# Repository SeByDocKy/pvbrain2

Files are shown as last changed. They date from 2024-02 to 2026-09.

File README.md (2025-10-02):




# PVbrainV2

pvbrain_v2_logo

> [!IMPORTANT]
> <sub></sub> is an open source/openhardware project to monitor/control __`SIMULTANEOUSLY`__ :
> - Multiple inverters. <sup>`(PIPsolar/Voltronic, Deye, Growatt, Sofar, Victron, etc...)`</sup> 
> - And multiple BMS. <sup>`(JKBMS, AntBMS, DalyBMS, SeplosBMS, Pylontech, etc...)`</sup>
> 
> <sup>-> _In theory any inverter or BMS with ESPhome support can be used with the PVbrain2._</sup>
> 
> It also adds the possibility of controlling up to 32 relays allowing for example to control an **A**utomatic **T**ransfer **S**witch <sup>(ATS)</sup> _(Offgrid<=>return to the network)_. 
> 
> The PCB uses only crossover components or pluggable components in order to have easy setup/maintenance. 
> 
> The MCU used is an [ESP32S3](https://s.click.aliexpress.com/e/_DCEPtOd) running <sub></sub> allowing communication over WiFi to <sub></sub> <sup>(HA)</sup> natively.<br/>
> <sup>-> _But </sup><sup> can be added easily._</sup>
> 
> __The main features are :__
> - [x] Direct communication and control with Voltronic/Pipsolar, DEYE, SOFAR, GROWATT inverters via direct Ethernet cable.<br/> <sup>_(pvbrain has a built-in [RS232](https://a.aliexpress.com/_EzMcqvP) and [RS485](https://a.aliexpress.com/_EzS7TkZ)  => TTL)_</sup>
> - [x] CANbus support. Possibility to translate informations from old generation BMS into modern CANbus protocols (Pylontech 1.2, Pylontech +, SMA, Victron)
> - [x] The VEdirect for <sub></sub> models with an insulated adapter provided. 
> - [x] Important settings can be set directly from HA <sup>_(or the web server if enabled)_</sup>.
> - [x] Monitor multiple BMS <sup>_(tested with JKBMS but should work with antBMS, DalyBMS, PaceBMS or SeplosBMS)_</sup> with an insulated adapter provided.
> - [x] Detect multiple AC sources <sup>_(solar/network/other)_</sup> via optocoupler modules (in order for example to do soft switching for the ATS part).
> - [x] Monitor _via_ a [JSY193](https://a.aliexpress.com/_EyMD1XJ), [JSY194T](https://a.aliexpress.com/_EHWOhZb) module <sup>_(modbus)_</sup> solar and network production.
> - [x] Monitor _via_ a [JSY231](https://aliexpress.com/item/1005007472236141.html), [Smartshunt](https://www.amazon.fr/VICTRON-ENERGY-SmartShunt-Contr%C3%B4leur-SHU050150050/dp/B0856PHNLX/ref=sr_1_1) module <sup>_(modbus)_</sup> and <sup>_(VE.direct)_</sup> battery energetic flows
> - [x] Control up to 32x relays with two i2c extension [SX1509](https://esphome.io/components/sx1509), _that is_ for ATS control or the reversing mode of a modern inverter.<br/> <sup>_(Axpert max I & II for example)_</sup>
> - [x] A solar power diverter for pure resistive loads (eg. hot water tank) thanks to [ROBOTDYN](https://a.aliexpress.com/_EwiP2jL) or [SSR](https://a.aliexpress.com/_EyikzBP) modules controlled in PWM, 0-10V. Can be easily extented for Modbus RTU model.
> - [x] Smart EVSE regulation _for_ a [ETEK ekepc2](https://fr.aliexpress.com/item/1005007472236141.html) module with AC active power, DC battery current or Pyranometer informations
> - [x] Monitor your basement temperature/humidity/pressure with [BME280](https://esphome.io/components/sensor/bme280) <sup>_(you can set up alarms just in case)_</sup>.
> - [x] Free I2C ports available for plugging in additional I2C sensors.
> - [x] SPI port is also available.

> [!NOTE]
> This PCB uses the excellent ESPhome integrations done by :
> - <sub></sub> (Many BMS and inverter).
> - <sub></sub> (Expansion cards [WK2132](https://www.dfrobot.com/product-2001.html) and [WK2168](../main/hardware/module_wk_2168/wk2168_3d_view.png) ).
> 
> The __PVbrain 2.0__ represents a joint work between <sub></sub> of the <sub></sub> and <sub></sub>.
> - With the help of several members of the <sub></sub>.

**For more information on the project, the pcb, the code and their use, please refer to the [wiki](https://github.com/SeByDocKy/pvbrain2/wiki).**

# Release PVbrain 2 Youtube Live event:
youtube_live (https://www.youtube.com/watch?v=e8uBhS54MFE)
<br/>_Video in French._

# Software (ESPhome) installation steps:
- __First of all be sure you have installed on your machine the ESP32 S3 driver from [Sillicon Labs](https://www.silabs.com/developers/usb-to-uart-bridge-vcp-drivers?tab=downloads).__

__Classic procedure :__

> <details>
><summary>Click here for show the Classic procedure. :arrow_heading_down:</summary>
> 
> :back:
> - :one: :heavy_minus_sign: Retrieve the [PVbrain 2.0](https://github.com/SeByDocKy/pvbrain2/archive/refs/heads/main.zip) zip (by right clicking) and save it into a new created folder, eg. /pvbrain2
> - :two: :heavy_minus_sign: Uncompress the zip file into your local folder (/pvbrain2) or into your/config/esphome folder of HASSIO (use samba share to transfer the uncompressed files).
> - :three: :heavy_minus_sign: Open your esphome's secrets.yaml file and check if wifi_ssid, wifi_password and ap_password variables are correctly corresponding with your local WiFi informations. 
> - :four: :heavy_minus_sign: Edit the PVbrain2.yaml and comment/uncomment each package according to your own solar setup. 
> - :five: :heavy_minus_sign: Compile and upload the code on your ESP32 S3 device.
> </details>

__Dummy procedure (for newbabies) :__

> <details>
><summary>Click here for show the Dummy procedure. :arrow_heading_down:</summary>
>
> :back:
> - :one: :heavy_minus_sign: Create/sign in a [Github](https://github.com/) accompt. You can create it faster with OAuth2 via your google account for example. 
> - :two: :heavy_minus_sign: Open the following [Gitpod](https://gitpod.io/#https://github.com/SeByDocKy/pvbrain2/tree/main) link. 
>   - The first time you will need also to sign in into gitpod framework for example with your previously created Github account.
> - :three: :heavy_minus_sign: When logged into Gitpod, you will see during the ESPhome installation, some log lines printed in the terminal. 
>   - Wait a couples of minutes to let finish the processus. 
>   - When done, press the "Open Browser" located at the botton right of the Gitpod page. 
>   - It should open a new webpage with the ESPhome Dashboard.
> - :four: :heavy_minus_sign: On the ESPhome Dashboard, click first on "secret" button located at the top right corner. 
>   - Replace "xxxxxxxx", "yyyyyyyy" and "zzzzzzzz" with your own WiFi SSID/password and AP informations (AP password will allow to access to your PVbrain2 if your WiFi/LAN is down). 
>   - Be aware, WiFi password must be a minimum of 8 caractars. 
>     - If not, you will need to change your WiFi password correspondly. 
>   - Click on "save" and quit the secret page by clicking on the top left cross.
> - :five: :heavy_minus_sign: Click on "Edit" for the PVbrain2 model. 
>   - Comment and/or uncomment each package according to your own solar setup and save the file. (Tip: you can comment/uncomment several lines simultaneously by selecting the lines and press on CTRL + /)
> - :six: :heavy_minus_sign: Plug your ESP32-S3 with a USB data cable first then the on top right corner, choose "Install" then on "Plug into this computer" to compile the firmware. It can be a long processus !!!. 
>   - Wait a couple of minutes (it first compile the code at background during 3-4min) then it starts the flashing part. 
>     - You should see a progression bar running when flashing.
> - :seven: :heavy_minus_sign: You finished the flashing procedure. 
>   - If you entered correctly your WiFi informations in the secrets.yaml file, you should see a notification in Home Assistant asking you to accept a new ESPhome device. 
>   - Accept it... __You finished!!!!__
> </details>

> <details>
><summary>Click here for show the French YouTube video of the Dummy procedure. :arrow_heading_down:</summary>
>
> :back:
>
> youtube_Dummy_procedure (https://www.youtube.com/watch?v=R9PXNV0ayU4)
> <br/>_Video in French._
> </details>

# Main PCB Layout :

| 3D View | Copper Area |
| :---: | :---: |
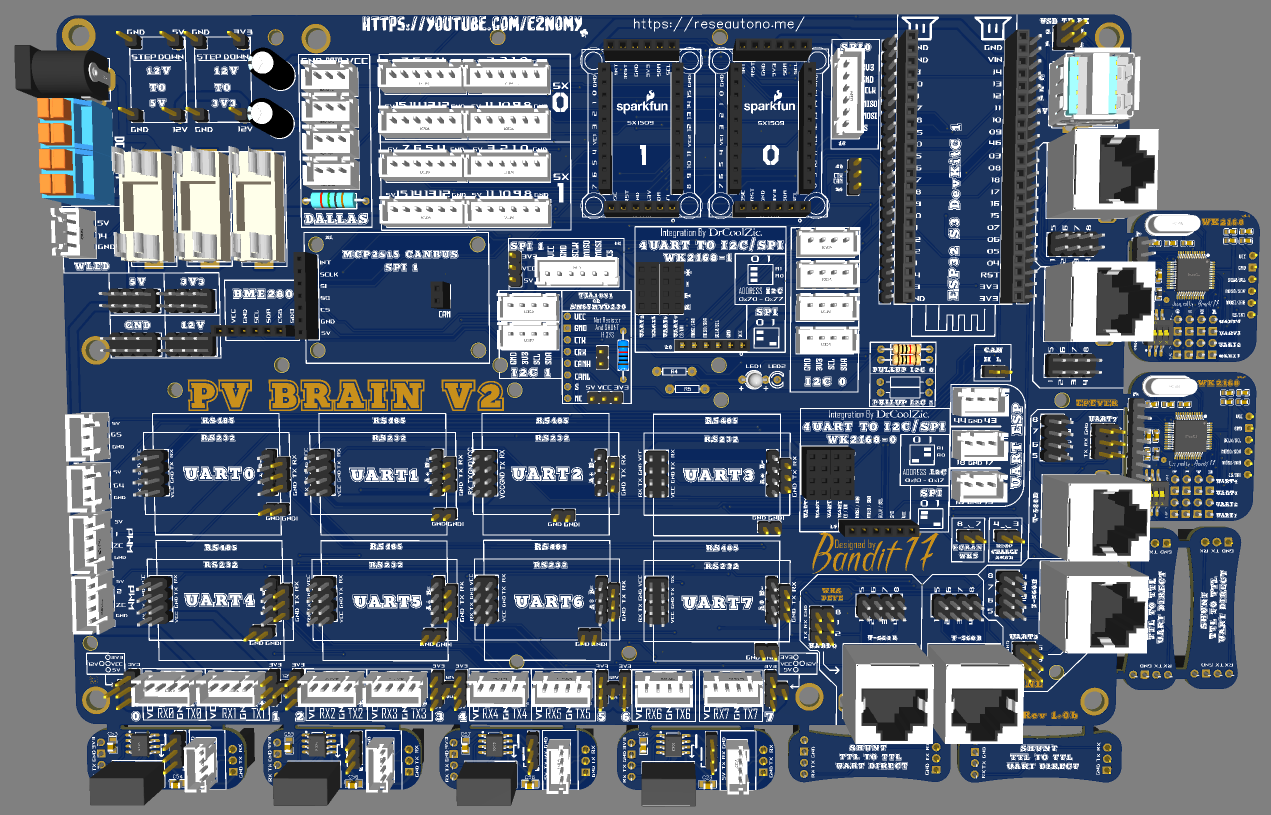
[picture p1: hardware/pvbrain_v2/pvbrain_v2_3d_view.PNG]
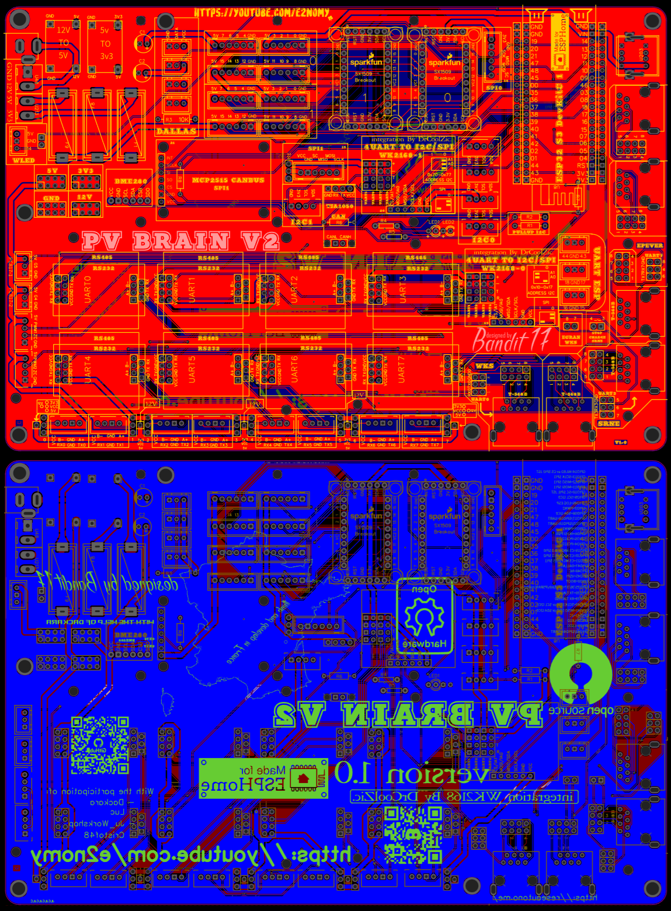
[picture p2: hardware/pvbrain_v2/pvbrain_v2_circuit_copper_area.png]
| |  |

<details>
<summary>Click here for show other views and schematic. :arrow_heading_down:</summary>

:back:
| Front | Back | Circuit |
| :---: | :---: | :---: |
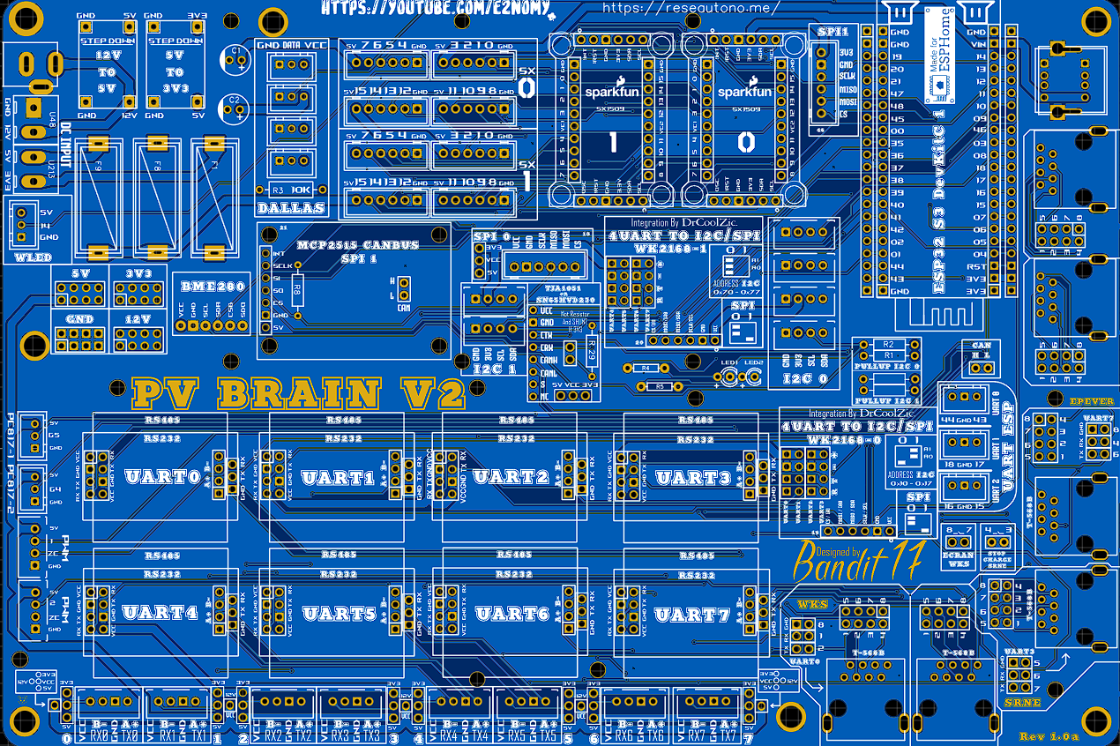
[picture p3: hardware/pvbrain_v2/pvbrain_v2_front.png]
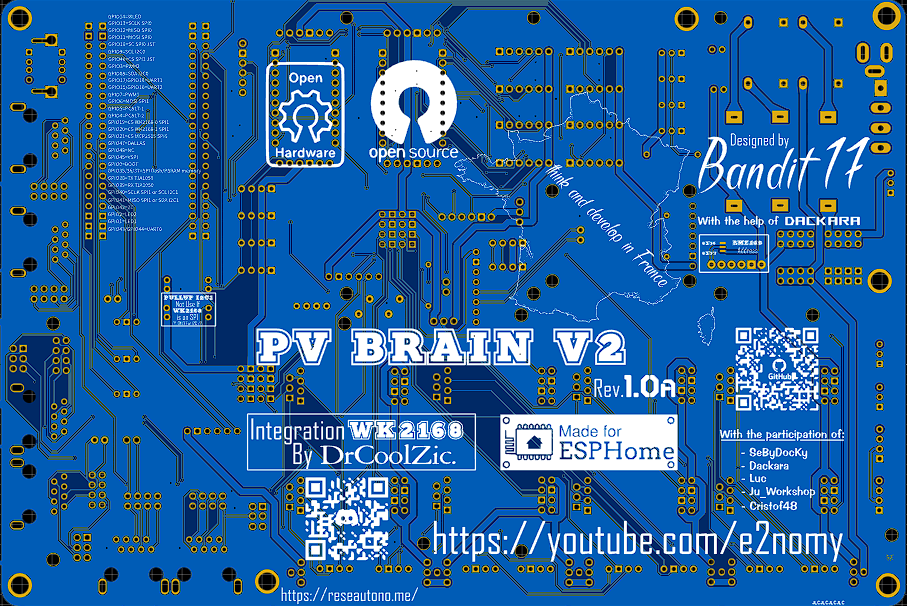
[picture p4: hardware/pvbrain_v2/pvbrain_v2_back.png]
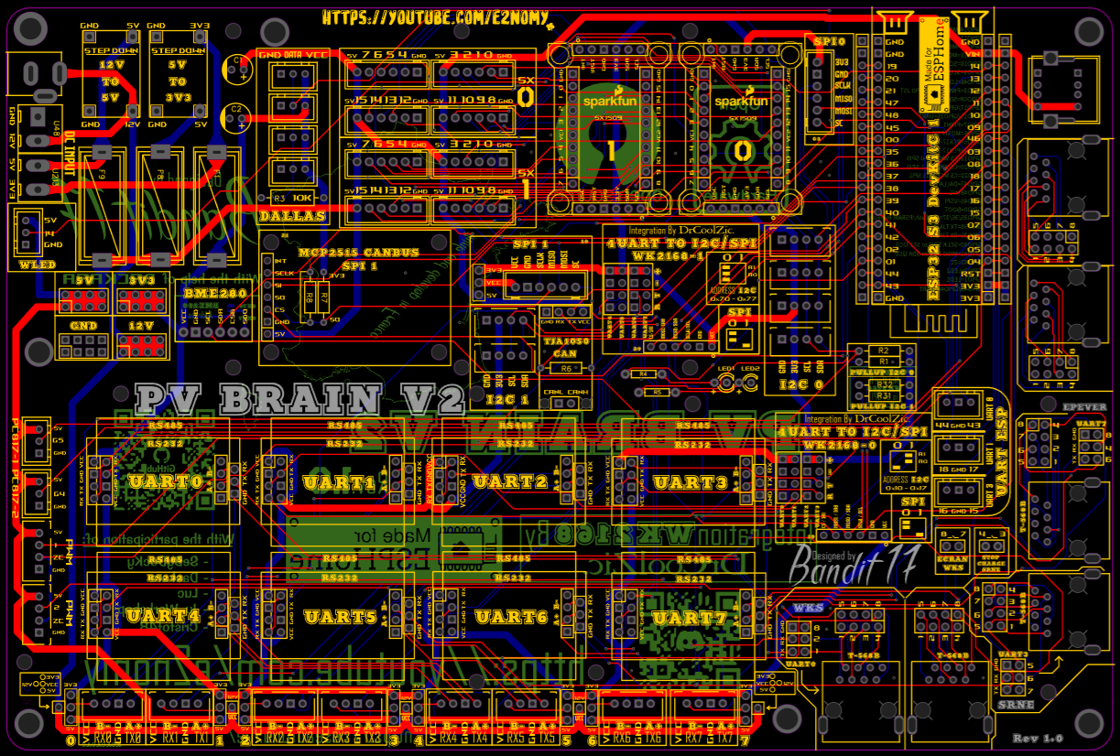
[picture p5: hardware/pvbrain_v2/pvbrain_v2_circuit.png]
|  |  |  |

| Schematic 1 | Schematic 2 |
| :---: | :---: |
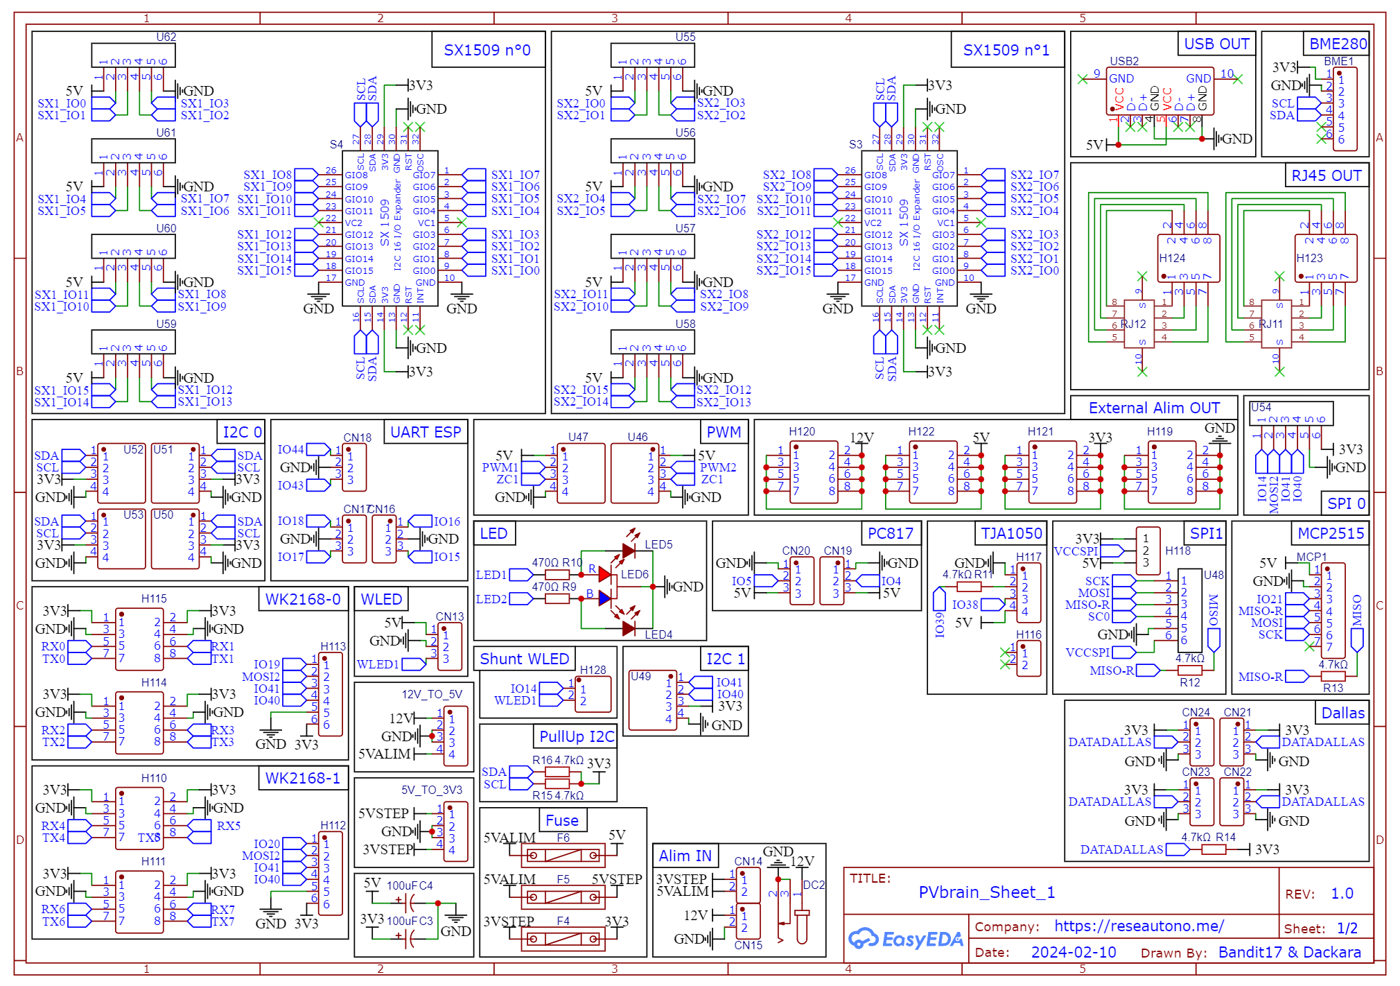
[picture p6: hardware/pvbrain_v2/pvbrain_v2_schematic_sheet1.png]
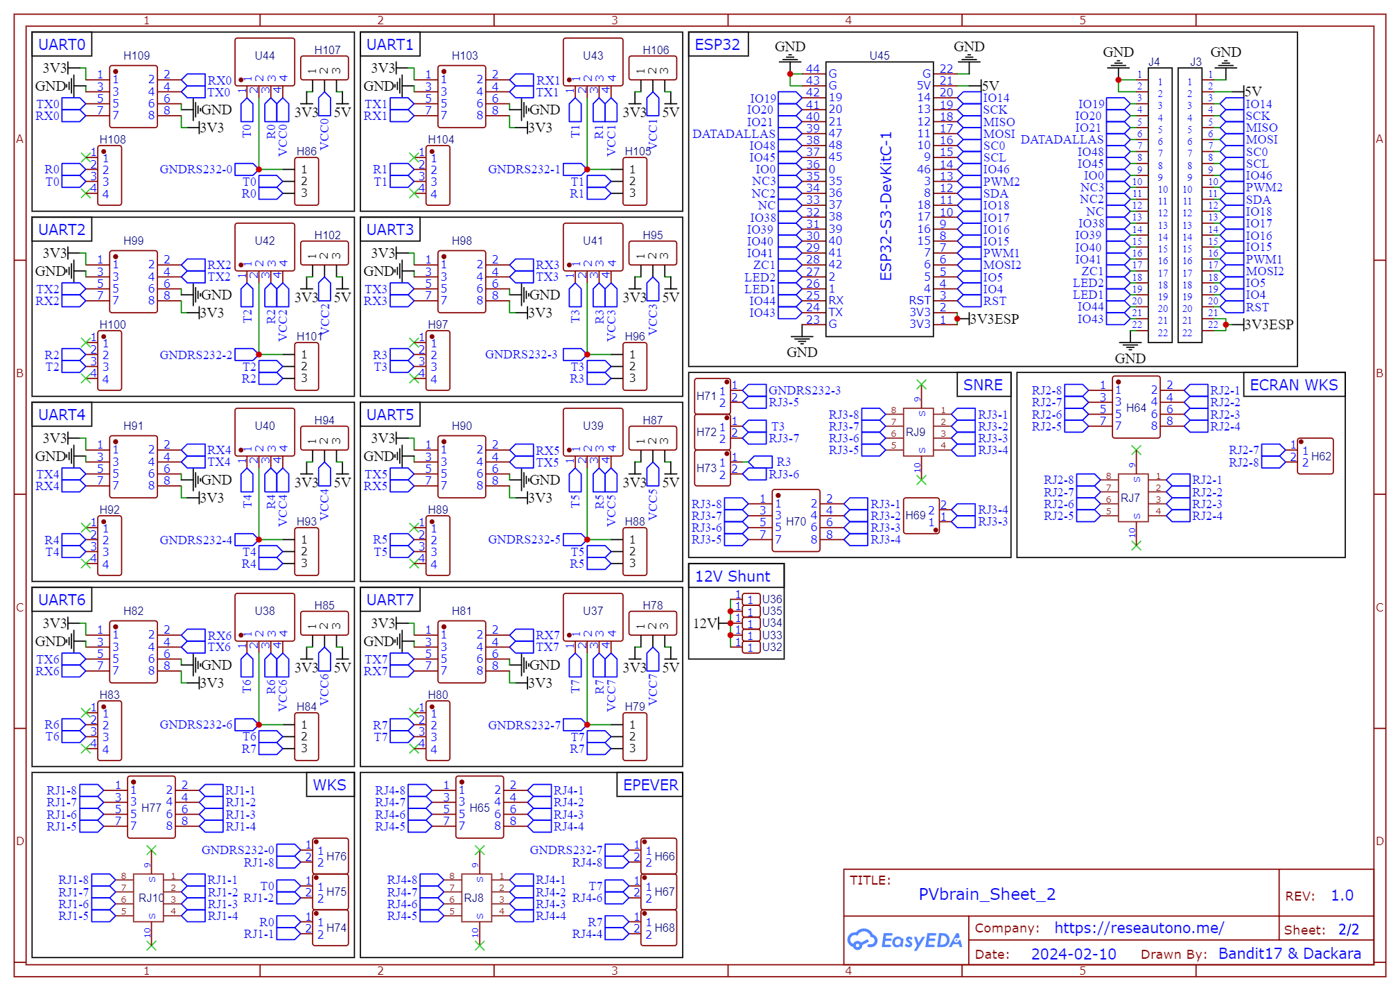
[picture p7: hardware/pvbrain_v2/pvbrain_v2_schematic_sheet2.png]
| |  |
</details>

## [Gerber files and BOM :](../main/hardware)

Please find all Gerber files required for the PCB in the following folder : [__Hardware__](../main/hardware).<br/>
Also, find all BOM <sup>_(Aliexpress and Amzon links)_</sup> and some extra information in this <sub></sub> <sup>_(in French)_</sup>.

# DIY module :
Special clip-on modules were created by <sub></sub> for use <sup>_(or not)_</sup> with the PVbrain.

## [WK 2168 :](../main/hardware/module_wk_2168)
Module to extend the number of uarts on an esp32 <sup>_(4 Uarts per card)_</sup> an 8 GPIO, possibility of communicating in I2C or SPI.
| 3D View | Schematic |
| :---: | :---: |
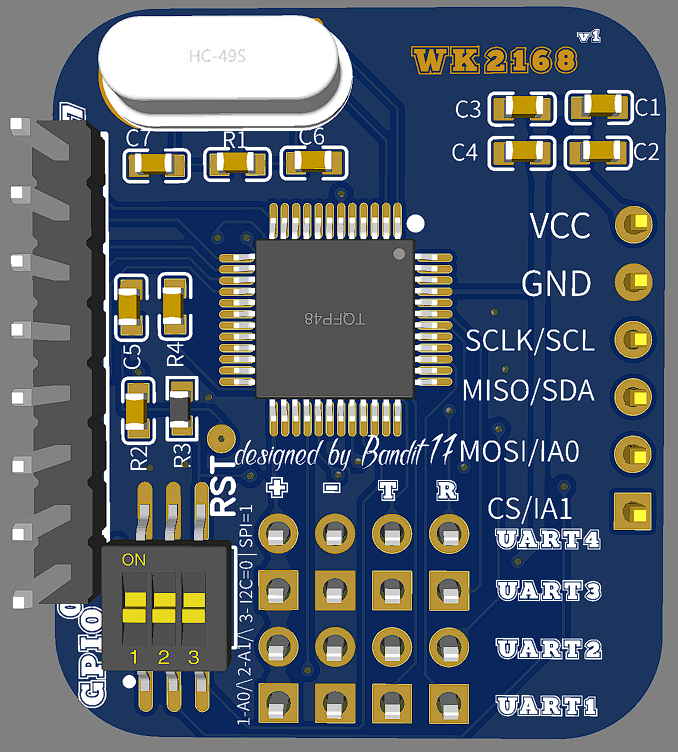
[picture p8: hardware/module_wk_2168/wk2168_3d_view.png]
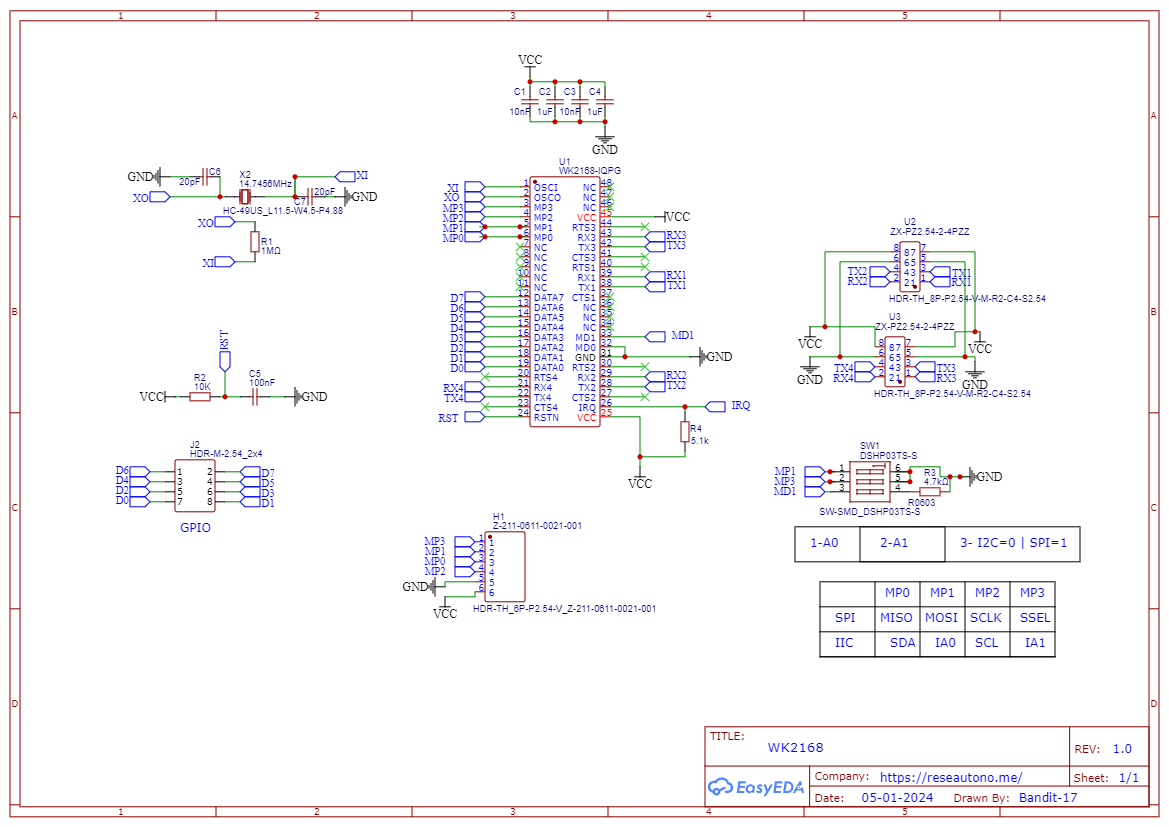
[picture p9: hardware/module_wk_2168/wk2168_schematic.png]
|  |  |

<details>
<summary>Click here for show other views. :arrow_heading_down:</summary>

:back:
| Front | Back | Circuit |
| :---: | :---: | :---: |
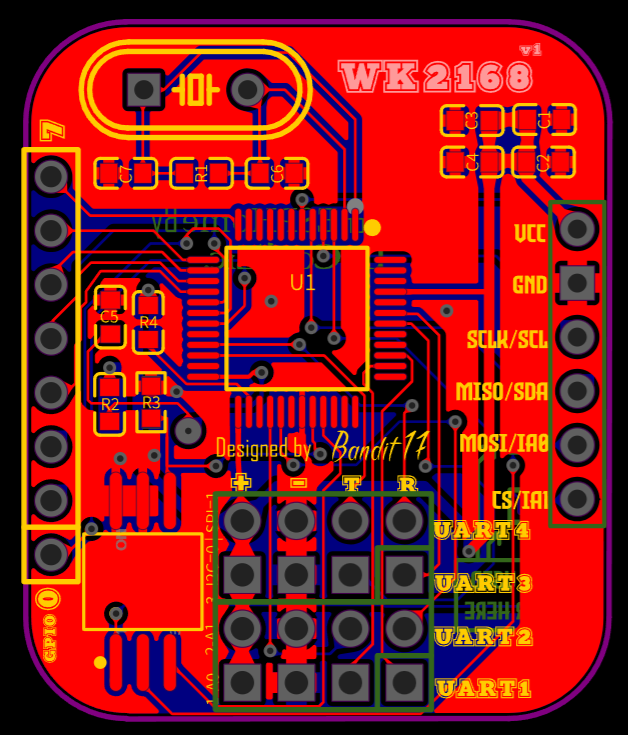
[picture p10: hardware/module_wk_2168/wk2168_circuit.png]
| |  |  |
</details>

## [WK 2132 :](../main/hardware/module_wk_2132)
Before discovering the WK2168 module which allowed the creation of the card above, a DIY version of the DFRobot [DFR0627](https://www.dfrobot.com/product-2001.html) had been designed.<br/>
Its cost is a little lower than its big brother the WK2168, but it only allows 2 additional UARTs.
| 3D View | Schematic |
| :---: | :---: |
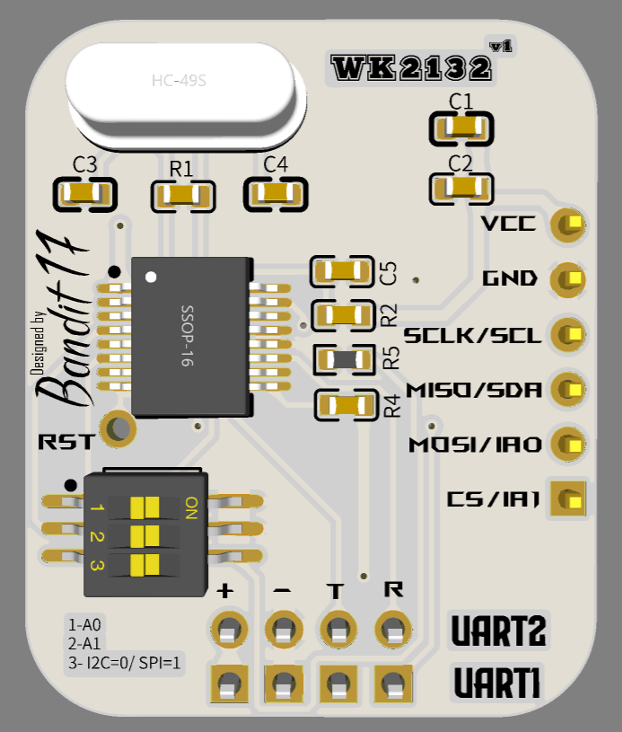
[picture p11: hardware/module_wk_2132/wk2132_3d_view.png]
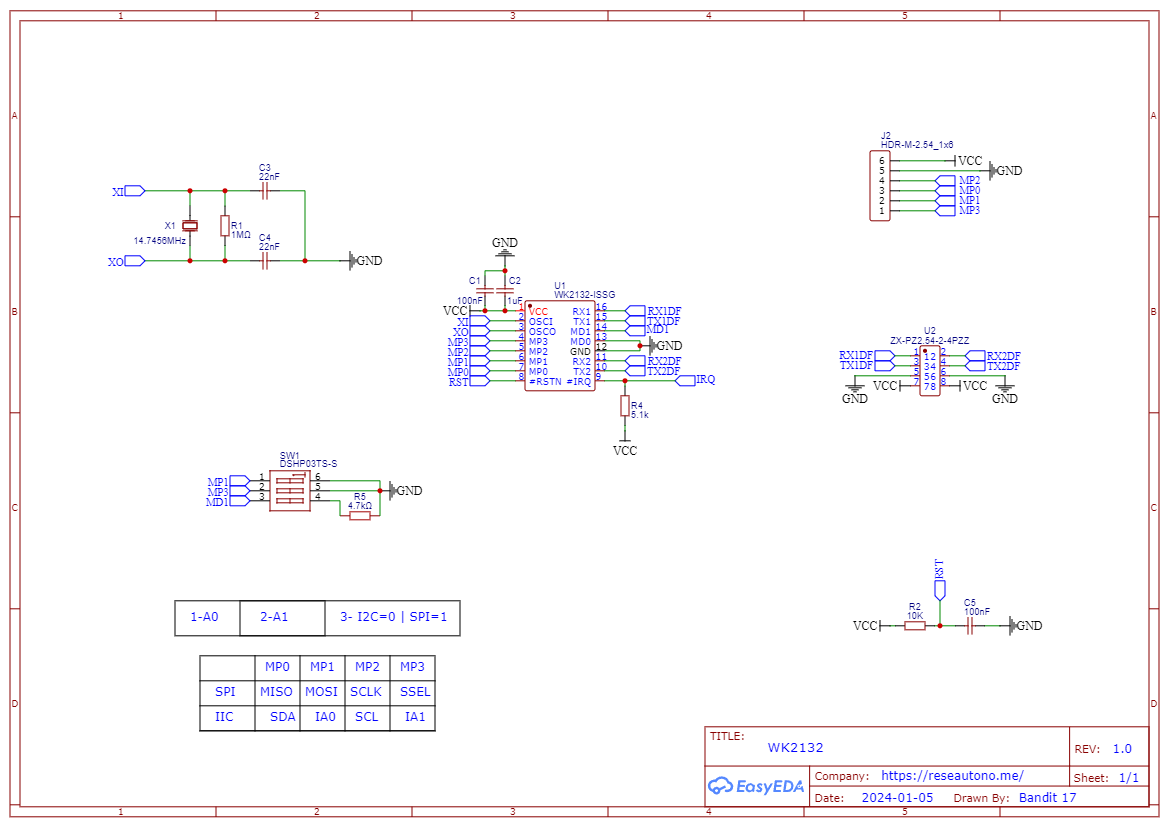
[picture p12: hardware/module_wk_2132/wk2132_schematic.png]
| |  |

## [UART Isolator :](../main/hardware/module_uart_isolator)
TTL isolator, originally designed for Victron VEdirect.
- With the participation of <sub></sub>, <sub></sub> and <sub></sub> of the <sub></sub>.

| 3D View | Schematic |
| :---: | :---: |
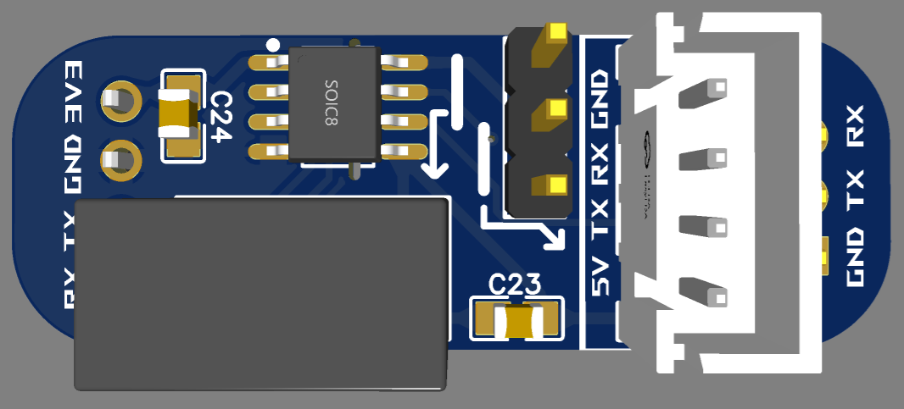
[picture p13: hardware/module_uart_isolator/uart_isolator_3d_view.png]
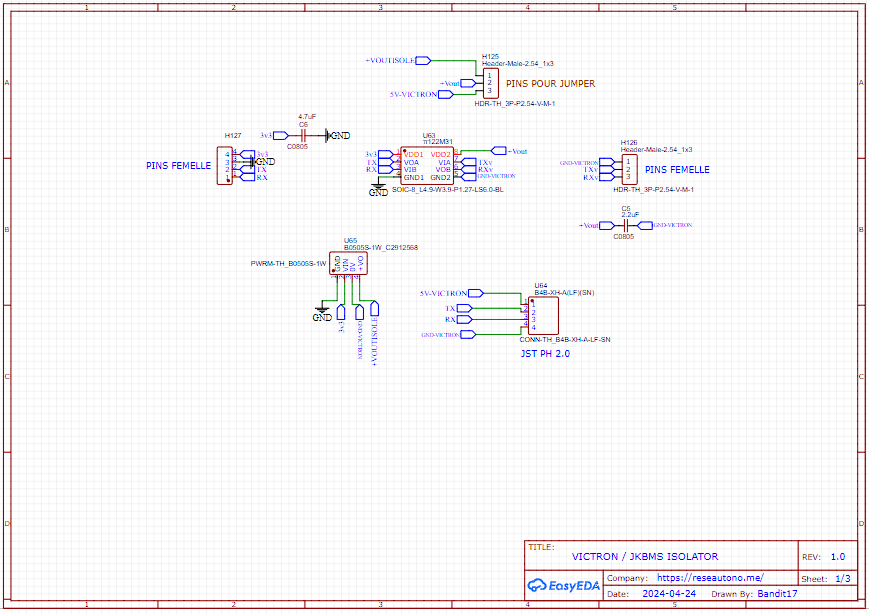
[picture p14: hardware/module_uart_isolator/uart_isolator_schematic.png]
| |  |

<details>
<summary>Click here for show other views. :arrow_heading_down:</summary>

:back:
| Front | Back | Circuit |
| :---: | :---: | :---: |
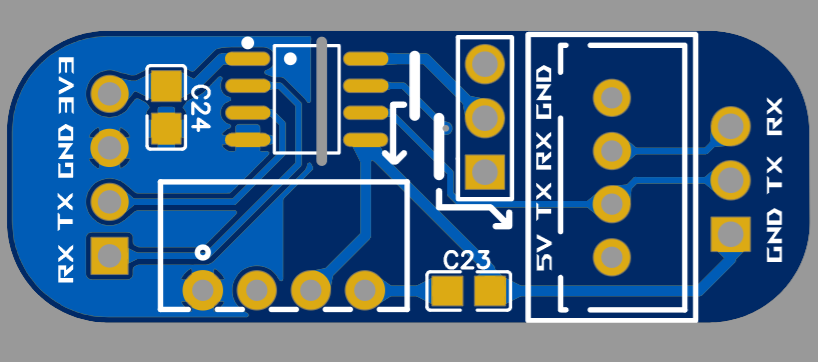
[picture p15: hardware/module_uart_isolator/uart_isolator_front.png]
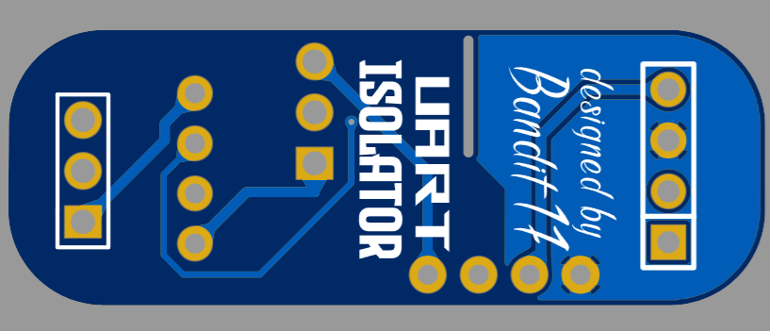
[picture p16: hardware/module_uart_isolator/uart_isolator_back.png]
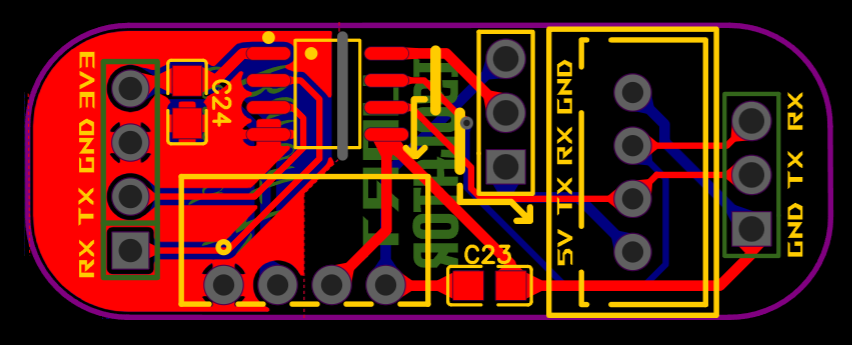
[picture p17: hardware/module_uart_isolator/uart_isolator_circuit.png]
|  |  |  |
</details>

## [Shunt TTL :](../main/hardware/module_shunt_ttl)
Simple Shunt for Direct UART output.
| Front | 3D View |
| :---: | :---: |
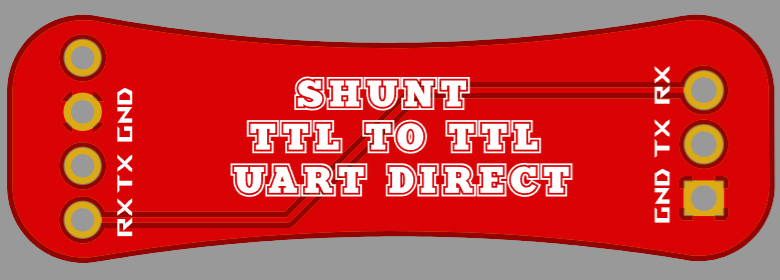
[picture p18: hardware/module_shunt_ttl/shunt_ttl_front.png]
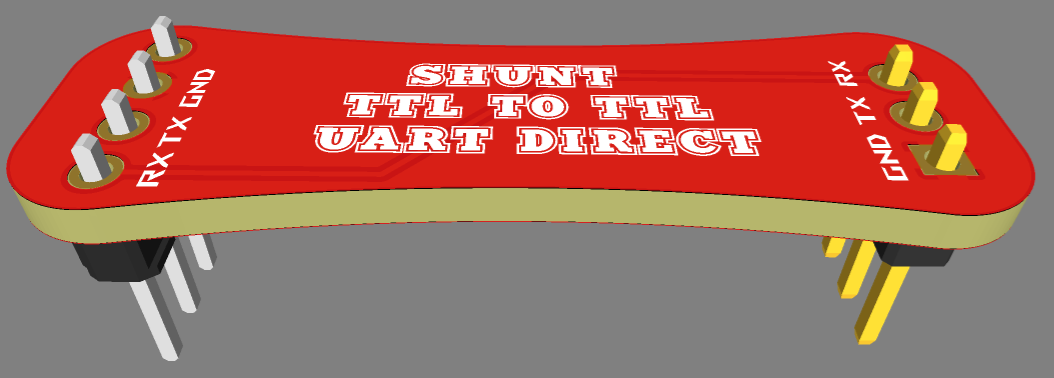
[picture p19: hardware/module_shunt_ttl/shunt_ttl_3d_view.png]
|  |  |

# Additional daughter boards addons:

## [UART Extension Module :](../main/hardware/addon_carte_uart_extension)
An optional addon card can be plugged to allowing 4 additional UART outputs.

| 3D View | Schematic |
| :---: | :---: |
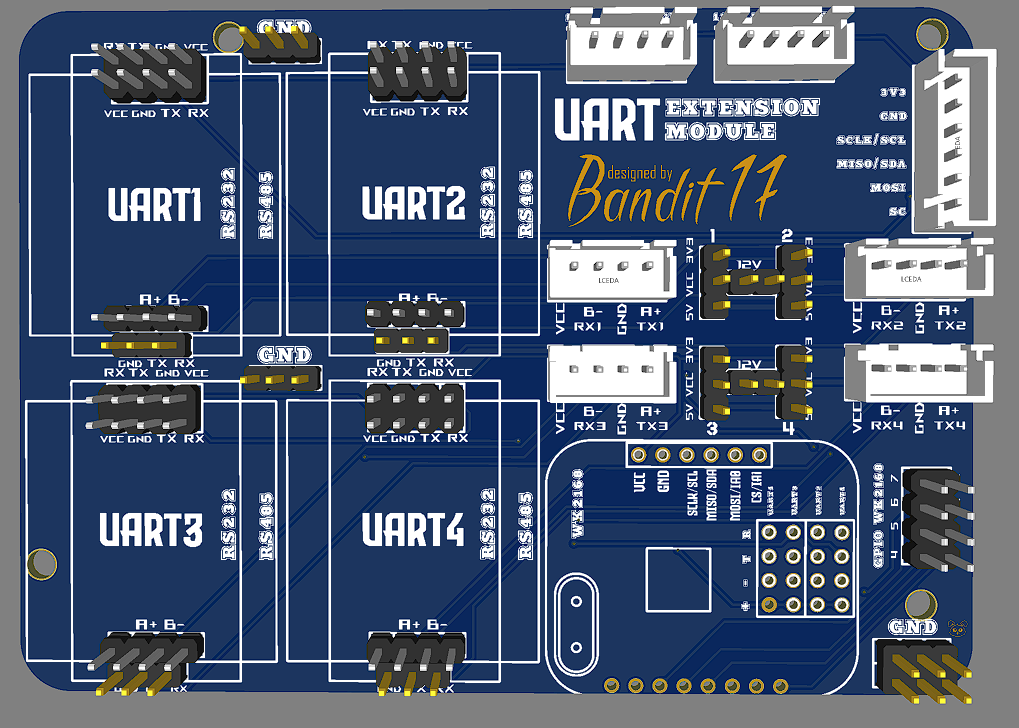
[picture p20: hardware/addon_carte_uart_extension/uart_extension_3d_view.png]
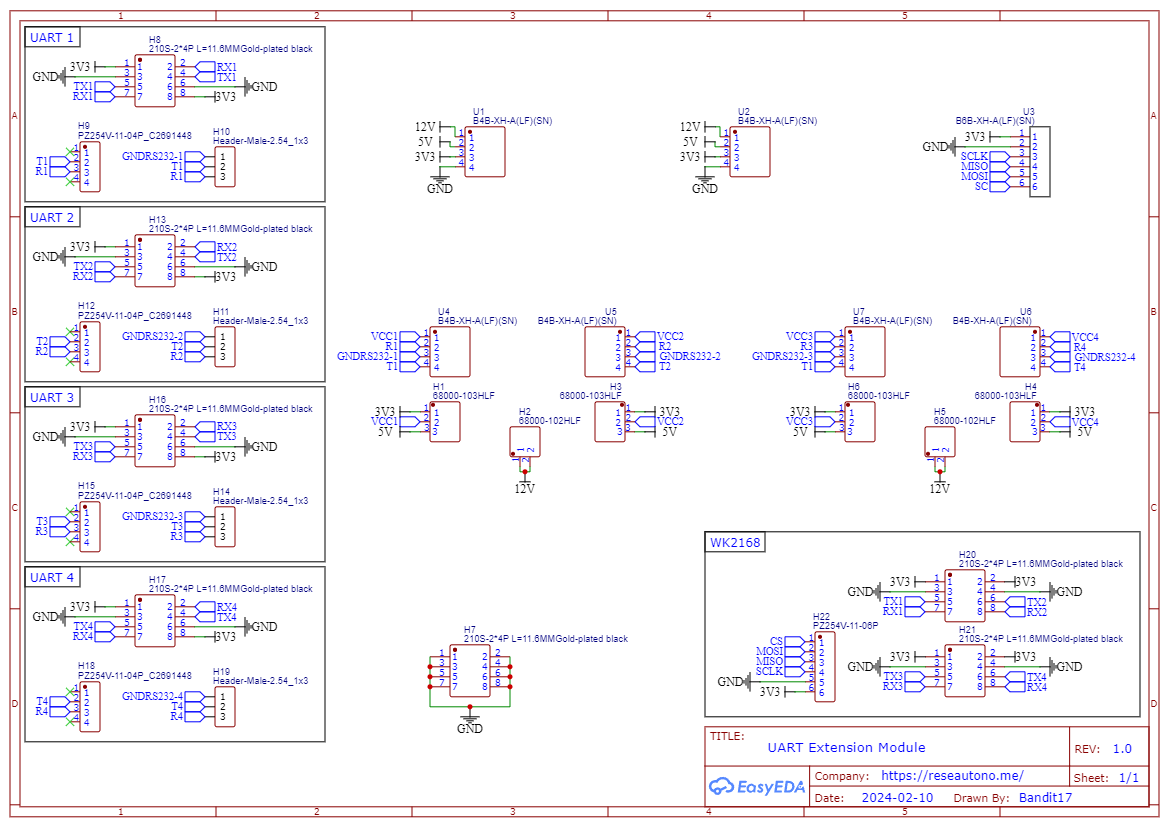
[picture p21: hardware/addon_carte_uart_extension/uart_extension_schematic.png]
|  |  |

<details>
<summary>Click here for show other views. :arrow_heading_down:</summary>

:back:
| Front | Back | Circuit |
| :---: | :---: | :---: |
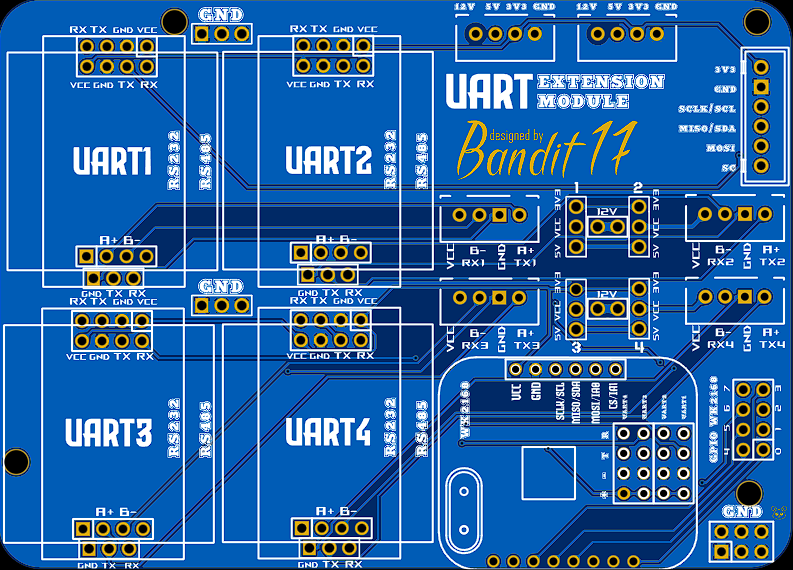
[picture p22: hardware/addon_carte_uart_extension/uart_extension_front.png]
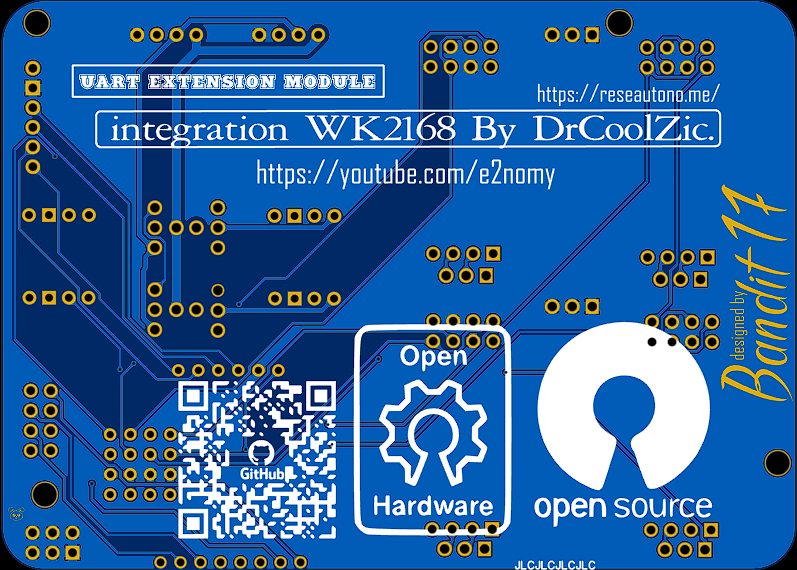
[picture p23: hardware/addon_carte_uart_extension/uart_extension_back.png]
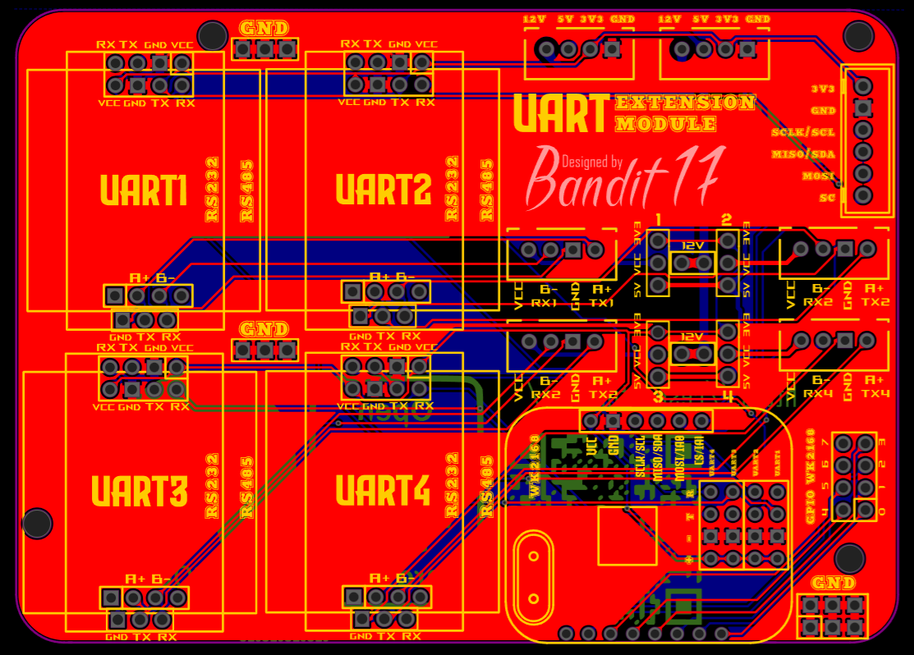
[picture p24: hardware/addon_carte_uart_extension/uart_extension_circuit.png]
|  |  |  |

Also, find all BOM <sup>_(Aliexpress and Amzon links)_</sup> and some extra information in this <sub></sub> <sup>_(in French)_</sup>.
</details>

## [MULTI-CAN :](../main/hardware/addon_MULTI-CAN)
An optional addon card can be plugged to allowing 4 additional CAN MODULE SPI.
| 3D View                   | 
| :-----------------------: |
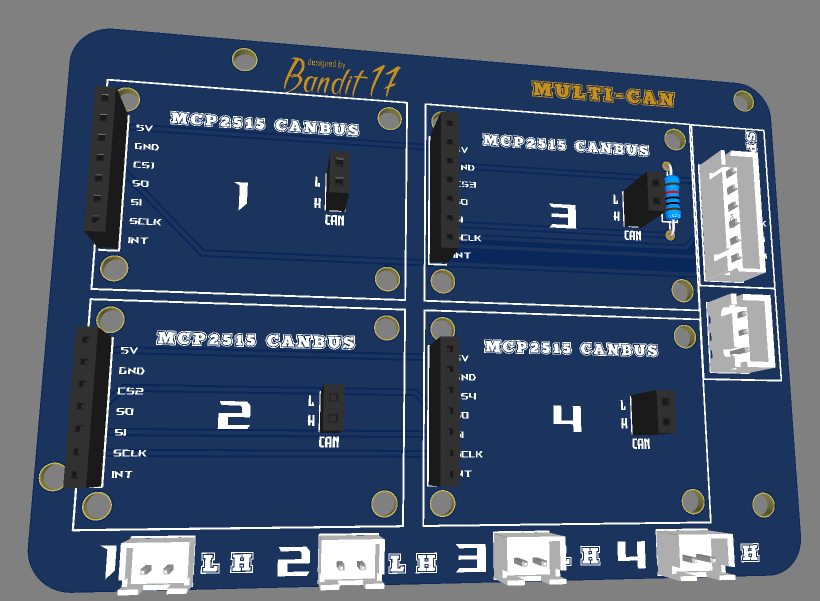
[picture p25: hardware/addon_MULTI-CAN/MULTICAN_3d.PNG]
|  |

<details>
<summary>Click here for show other views. :arrow_heading_down:</summary>

:back:
| Front | Back |
| :---: | :---: |
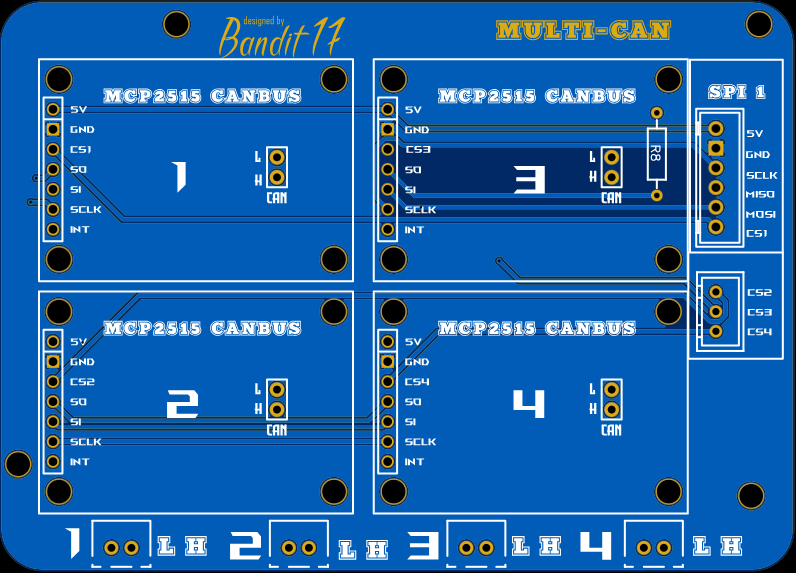
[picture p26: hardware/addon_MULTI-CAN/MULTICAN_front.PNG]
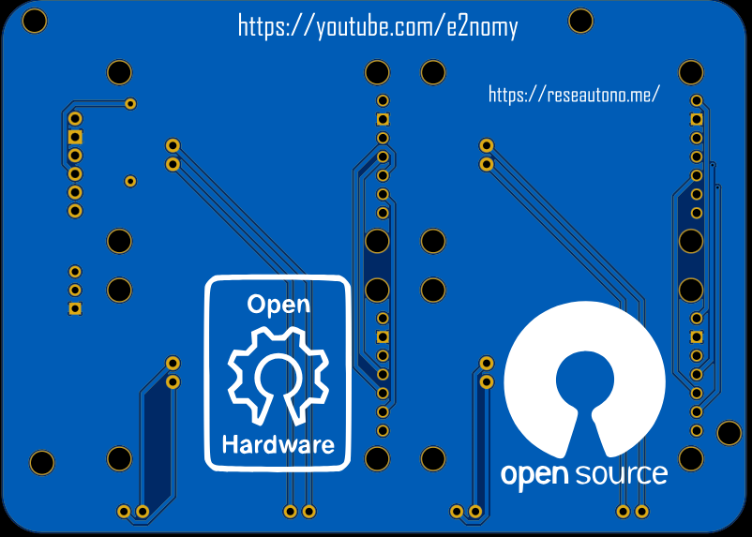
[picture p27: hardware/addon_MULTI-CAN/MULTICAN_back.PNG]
|  |  |

Also, find all BOM <sup>_(Aliexpress and Amzon links)_</sup> and some extra information in this <sub></sub> <sup>_(in French)_</sup>.
</details>

## [PV Monitor :](../main/hardware/addon_carte_pv_monitor)
Addon card created for [PVbrain V1](https://github.com/Bandit-17/PVBRAIN) by <sub></sub> and re-designed by <sub></sub> in this __V2__.

The card offers the possibility of securely monitoring the voltage of two DC inputs.

| 3D View | Schematic |
| :---: | :---: |
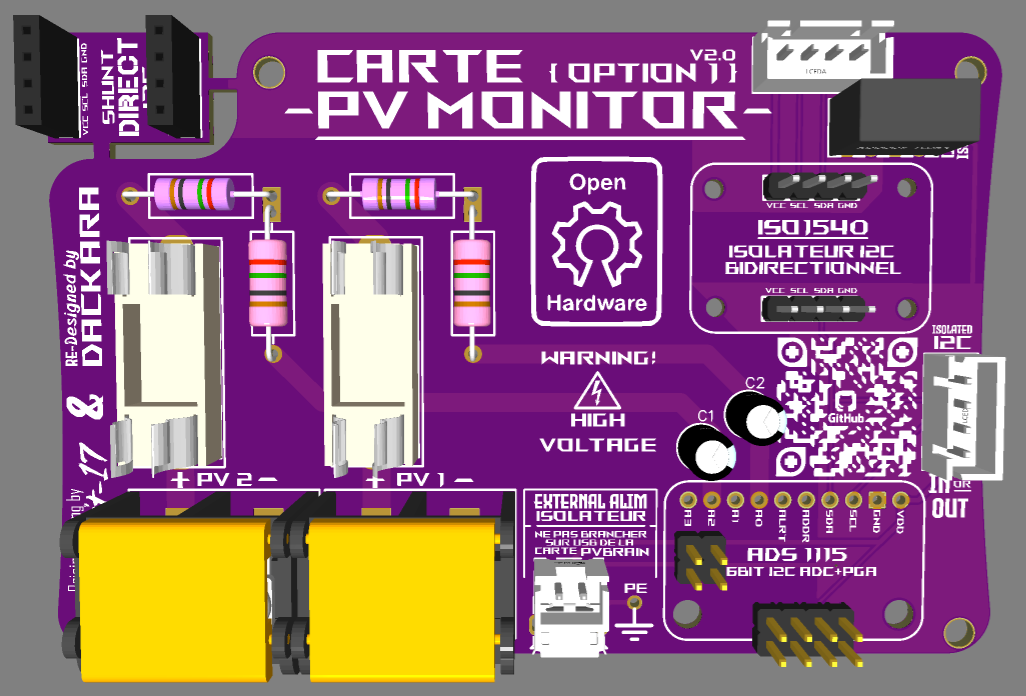
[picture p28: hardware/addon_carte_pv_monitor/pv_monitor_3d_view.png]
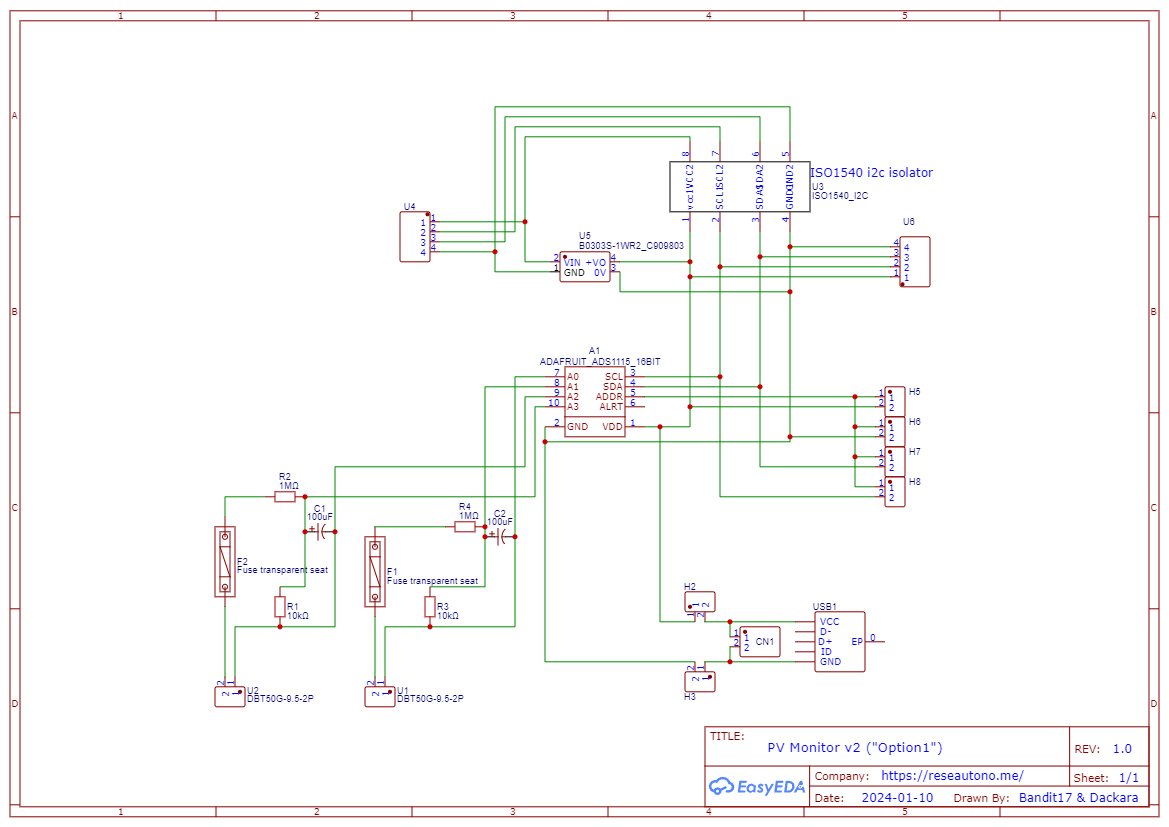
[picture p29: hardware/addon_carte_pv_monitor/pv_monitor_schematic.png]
| |  |

<details>
<summary>Click here for show other views. :arrow_heading_down:</summary>

:back:
| Front | Back | Circuit |
| :---: | :---: | :---: |
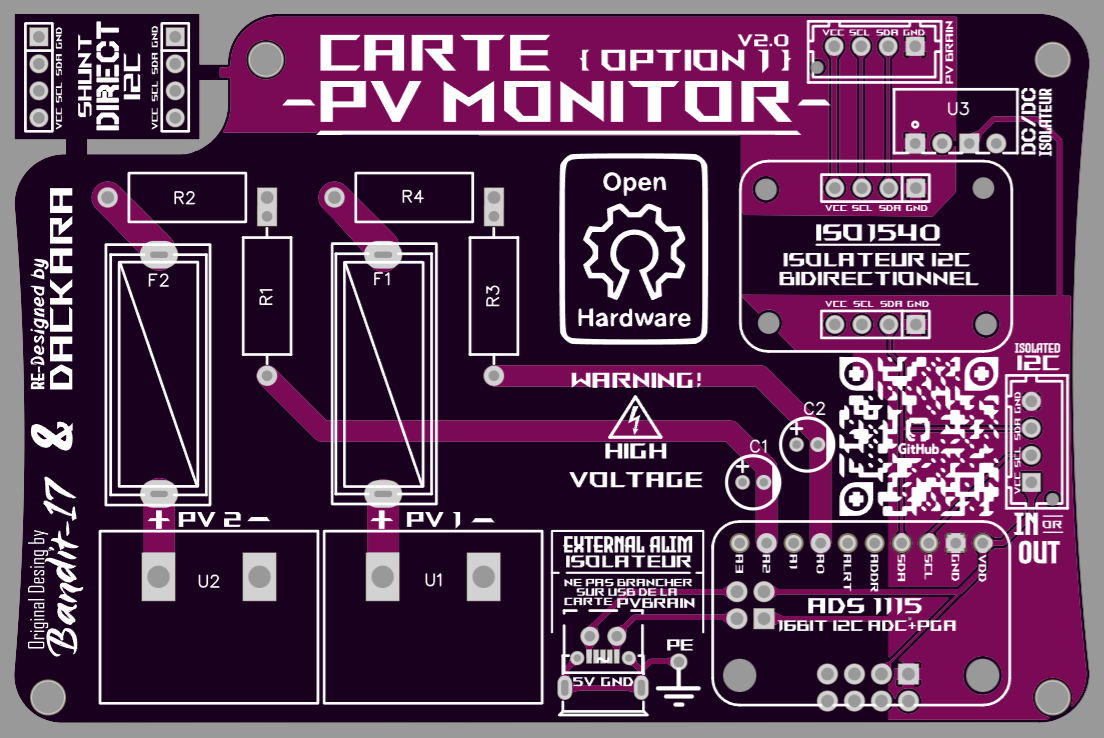
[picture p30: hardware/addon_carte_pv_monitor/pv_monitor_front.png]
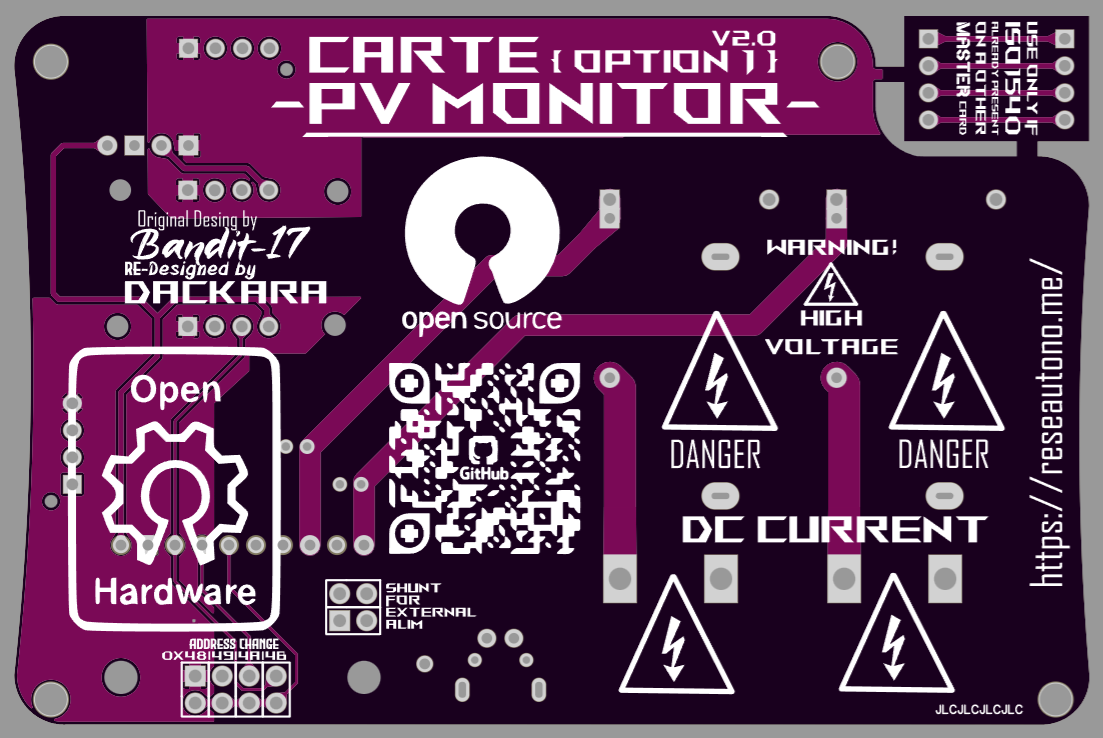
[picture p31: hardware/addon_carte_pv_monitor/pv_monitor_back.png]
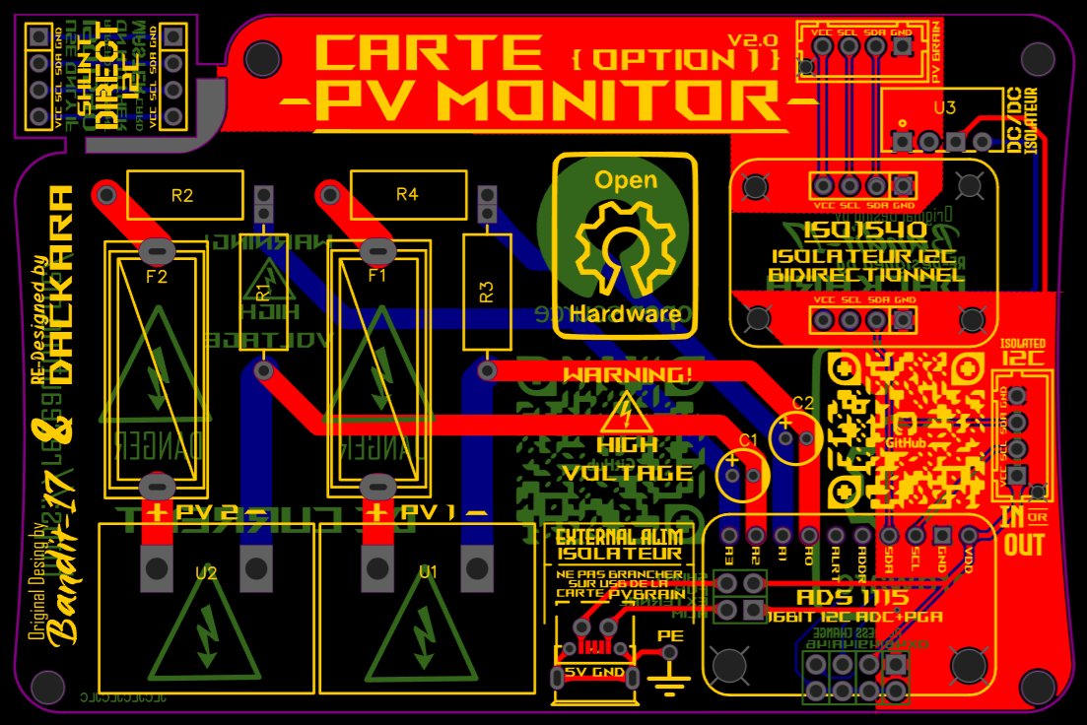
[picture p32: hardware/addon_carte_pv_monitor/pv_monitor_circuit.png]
|  |  |  |

Also, find all BOM <sup>_(Aliexpress and Amzon links)_</sup> and some extra information in this <sub></sub> <sup>_(in French)_</sup>.
</details>

## [Fil_Pilote :](../main/hardware/addon_carte_fil_pilote)
An additional card was created by <sub></sub> to allow control of the heating radiator pilot wire from the I2C port <sup>(4 output heating zones, control of 6 orders, possible to pair 2 cards and three-phase operation possible)</sup> and as an option , communication with Linky meters.

Link to the Github Page: <sub></sub>.

| 3D View | Photography |
| :---: | :---: |
|  |  |

## [Clamp_Meter :](../main/hardware/addon_carte_clamp_meter)
Another option card created by <sub></sub> to monitor the passage of current through the clamps.
- 1 to 16 Clamp <sup>(2 mounting possible for each output : JST-XH for [2-strand clamp](https://s.click.aliexpress.com/e/_De0j7rx) or Jack for [SCT013](https://s.click.aliexpress.com/e/_DFRTWIN))</sup>
- 1 to 4 pre-addressed [ADS1115](https://s.click.aliexpress.com/e/_DF9geSz).
- 1 [TCA9548A](https://s.click.aliexpress.com/e/_DDACktb) <sup>(optional - bridging if not used)</sup> to multiplex the I2C <sup>(useful in the event of more than 4 ADS or I2C address conflict)</sup> with all its outputs remote for external use.
- 1 ESP possible at input for non-PVbrain users or other reasons... 6 assembly possible: <sup>(offset of all outputs and recovery of i2c via bridging)</sup>.

| [ESP8266 D1 Mini](https://s.click.aliexpress.com/e/_DmbvqH7) | [ESP32 D1 Mini](https://s.click.aliexpress.com/e/_DEU8tVB) | [ESP32 S2 Mini](https://s.click.aliexpress.com/e/_DdgwMVF) | [ESP32 C3](https://s.click.aliexpress.com/e/_DFystRx) | [ESP32 C3 Zero](https://s.click.aliexpress.com/e/_DeIlFtn) | [ESP32 S3 Zero](https://s.click.aliexpress.com/e/_DeIlFtn) |
| :---| :---: | :---: | :---: | :---: |---: |
  
Link to the Github Page: <sub></sub> <sup>(Still in development)</sup>

| 3D View | Circuit |
| :---: | :---: |
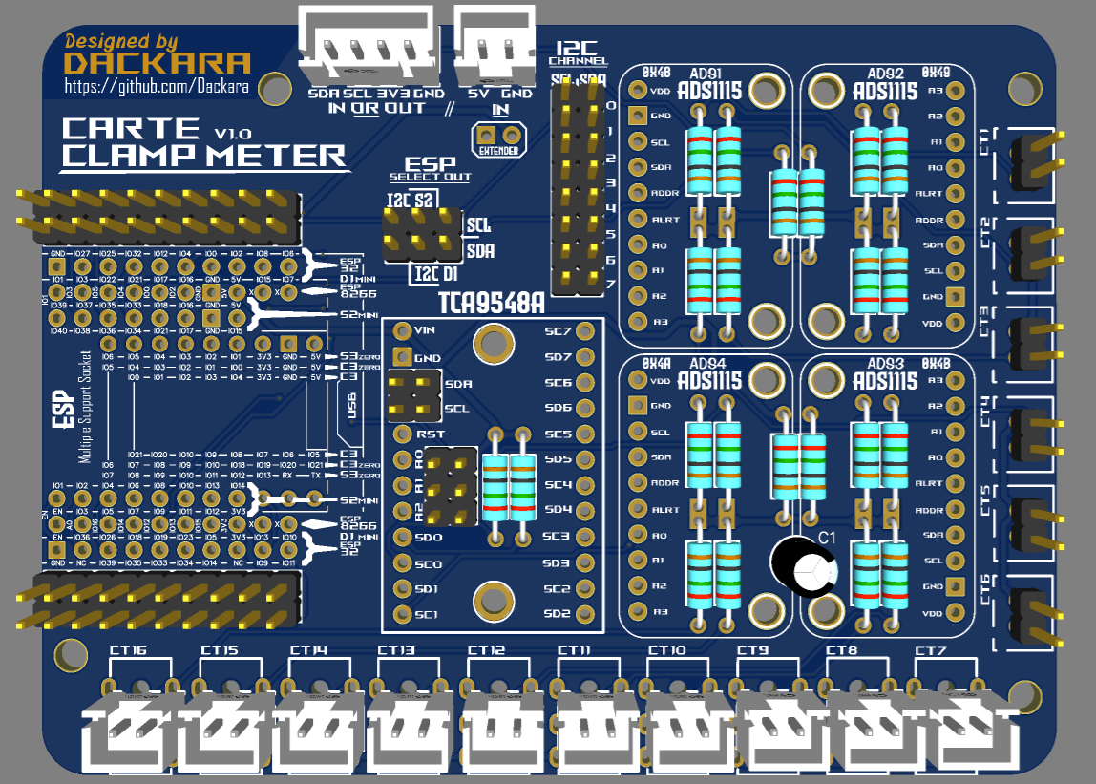
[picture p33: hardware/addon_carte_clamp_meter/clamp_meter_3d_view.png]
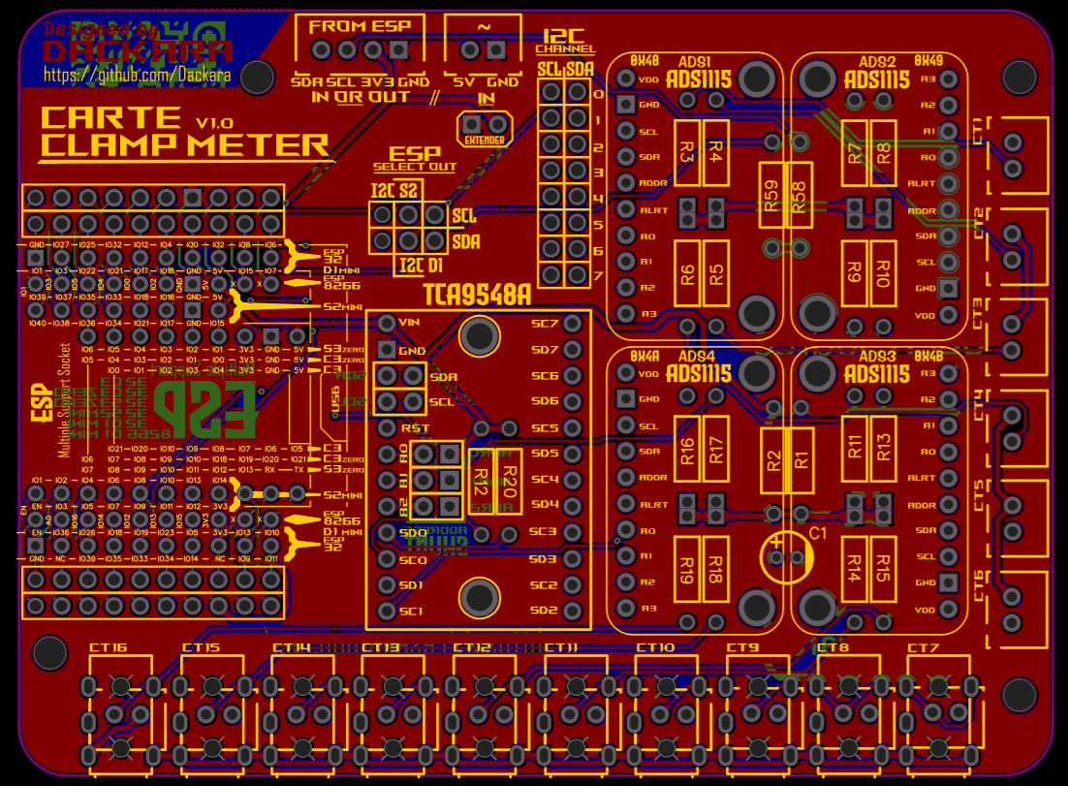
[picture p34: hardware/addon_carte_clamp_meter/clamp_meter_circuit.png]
| |  |

## [Protoboard :](../main/hardware/addon_carte_prototype)
Just a prototyping board with the same footprint as the other addon boards.
| Front                     |
| :-----------------------: |
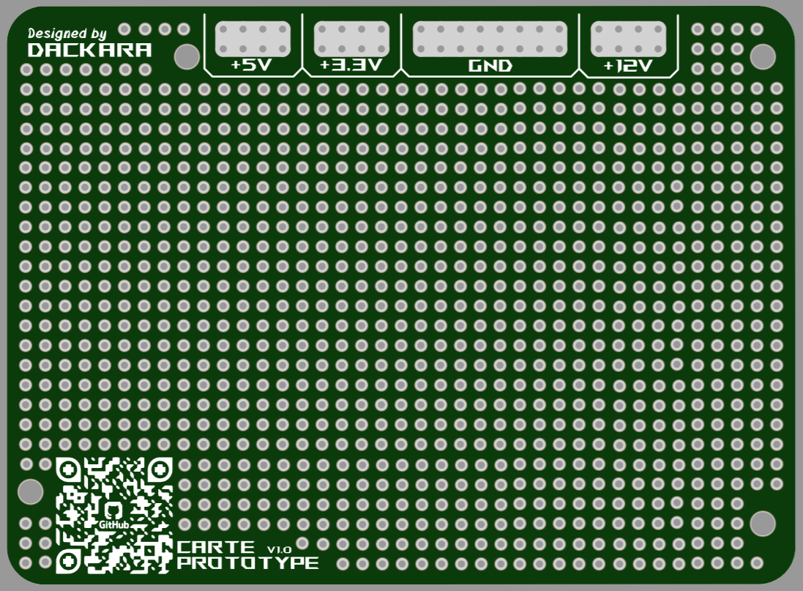
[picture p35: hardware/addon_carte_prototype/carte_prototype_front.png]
| |

## [3D print DIN mount :](../main/hardware/printable_3d_din_mount)
[3D Files](https://github.com/Dackara/Fil_Pilote/blob/main/Hardware/3D_Print) to print, created by <sub></sub>, for mounting addon cards on DIN rail <sup>(electrical panel)</sup>.<br/>
A plastic card in the same format as the addon cards which can, for example, allow circuit isolation, is also available.
| Front View | Back View |
| :---: | :---: |
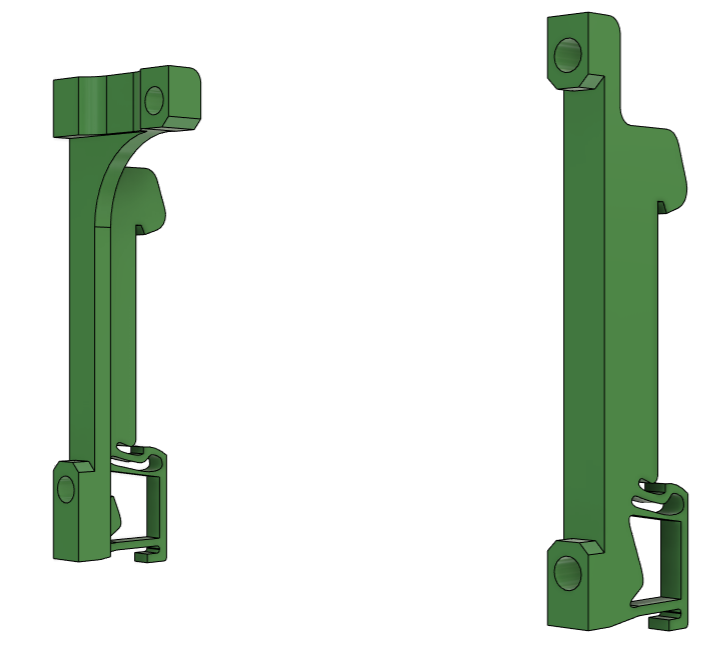
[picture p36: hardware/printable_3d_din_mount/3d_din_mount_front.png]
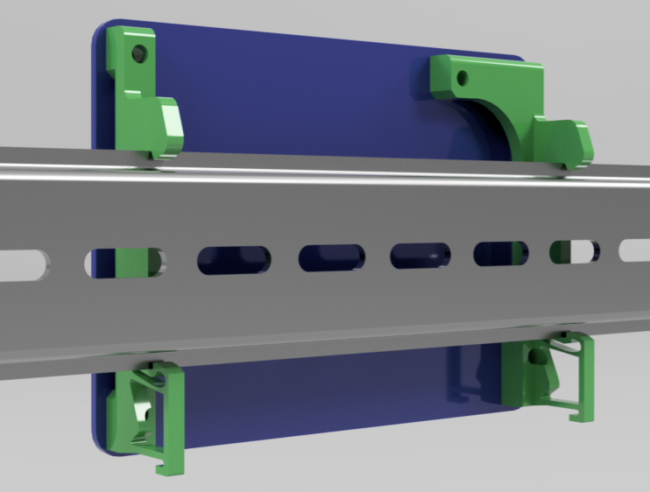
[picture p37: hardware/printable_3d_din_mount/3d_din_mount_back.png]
|  |  |

## ["Carte Option 2" :](../main/hardware/addon_carte_old_option2)
The old "Option 2" card made by <sub></sub> for the [PVbrain V1](https://github.com/Bandit-17/PVBRAIN) is also compatible with the __PVbrain V2__.
| 3D View                   |
| :-----------------------: |
| |

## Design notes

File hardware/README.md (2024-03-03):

# Tree Structure
>  Clic to the link for find all files.
## PVBrain V2 Main Board
- [Main PCB](../hardware/pvbrain_v2) (alone Main Board)
- Main PCB [with WK2168 and UART Isolator](../hardware/pvbrain_v2/pvbrain_v2_with_wk2168_isolator_shunt)
## Optional DIY module
- [WK2168](../hardware/module_wk_2168) (add 4 UART via I2C or SPI)
- [WK2132](../hardware/module_wk_2132) (add 2 UART via I2C or SPI)
- [UART Isolator](../hardware/module_uart_isolator) (UART isolator -ex: for Victron VEdirect)
- [Shunt TTL](../hardware/module_shunt_ttl) (direct output on main board)
## Optional Addon card
- [UART extension](../hardware/addon_carte_uart_extension) (alone Main Board)
  - UART extension [with UART Isolator](../hardware/addon_carte_uart_extension/uart_extention_with_isolator-victron)
- [PV Monitor](../hardware/addon_carte_pv_monitor) (was called "Option 1" on PVBrain v1)
- [Fil Pilote](../hardware/addon_carte_fil_pilote)
- [Clamp Meter](../hardware/addon_carte_clamp_meter)
- [Protoboard](../hardware/addon_carte_prototype)
> *Old ["Option 2"](../hardware/addon_carte_old_option2) of the PVbrain V1 (also compatible)*
## 3D print
- [DIN Rail Mount](../hardware/printable_3d_din_mount) (For Addon cards)

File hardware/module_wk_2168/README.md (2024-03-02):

## [WK 2168 :](../main/hardware/module_wk_2168)
Module to extend the number of uarts on an esp32 <sup>_(4 Uarts per card)_</sup> possibility of communicating in I2C or SPI.
| 3D View | Schematic |
| :---: | :---: |
|  |  |

| Front | Back | Circuit |
| :---: | :---: | :---: |
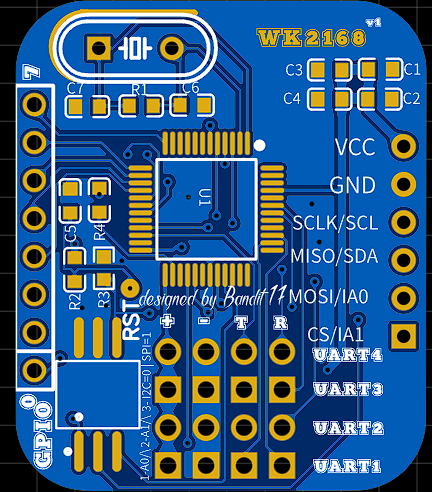
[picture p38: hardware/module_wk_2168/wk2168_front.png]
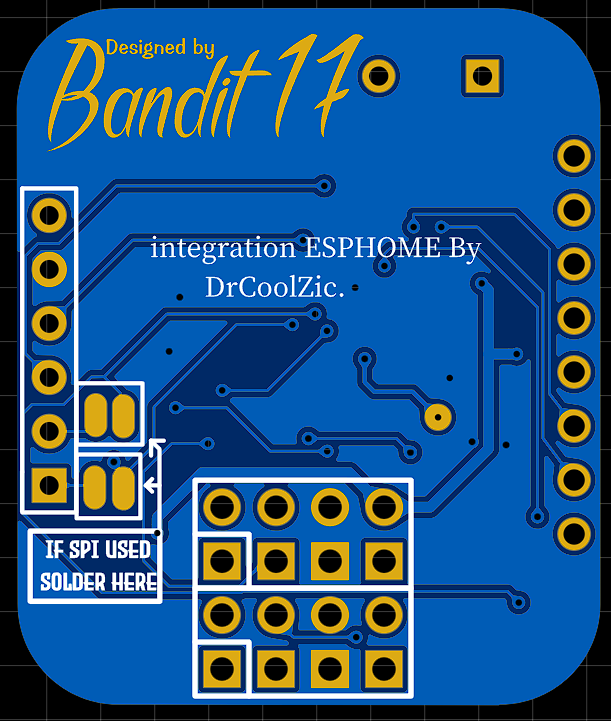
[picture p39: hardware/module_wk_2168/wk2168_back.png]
| |  |  |

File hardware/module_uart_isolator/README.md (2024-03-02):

## [UART Isolator :](../main/hardware/module_uart_isolator)
TTL isolator, originally designed for Victron VEdirect.
- With the participation of <sub></sub>, <sub></sub> and <sub></sub> of the <sub></sub>.

| 3D View | Schematic |
| :---: | :---: |
| |  |

| Front | Back | Circuit |
| :---: | :---: | :---: |
|  |  |  |

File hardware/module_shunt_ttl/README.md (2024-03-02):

## [Shunt TTL :](../main/hardware/module_shunt_ttl)
Simple Shunt for Direct UART output.
| Front | 3D View |
| :---: | :---: |
|  |  |

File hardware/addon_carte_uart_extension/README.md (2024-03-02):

## [UART Extension Module :](../main/hardware/addon_carte_uart_extension)
An optional addon card can be plugged to allowing 4 additional UART outputs.

| 3D View | Schematic |
| :---: | :---: |
|  |  |

| Front | Back | Circuit |
| :---: | :---: | :---: |
|  |  |  |

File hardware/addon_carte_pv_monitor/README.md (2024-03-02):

## [PV Monitor :](../main/hardware/addon_carte_pv_monitor)
Addon card created for [PVbrain V1](https://github.com/Bandit-17/PVBRAIN) by <sub></sub> and re-designed by <sub></sub> in this __V2__.

The card offers the possibility of securely monitoring the voltage of two DC inputs.

| 3D View | Schematic |
| :---: | :---: |
| |  |

| Front | Back | Circuit |
| :---: | :---: | :---: |
|  |  |  |

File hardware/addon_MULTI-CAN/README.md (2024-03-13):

## [MULTI-CAN :](../main/hardware/addon_MULTI-CAN)
An optional addon card can be plugged to allowing 4 additional CAN MODULE.

| 3D View                   | 
| :-----------------------: |
|  |

| Front | Back |
| :---: | :---: |
|  |  |

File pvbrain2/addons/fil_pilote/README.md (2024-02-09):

# Carte Option `Fil_Pilote`
Pour en savoir d'avantage sur la carte Optionel `Fil_Pilote`, rendez-vous sur le Github de .



## Le Fil Pilote, qu'est-ce que c'est ? A quoi ça sert ?
Le "Fil Pilote" est un système Français inventé dans les années 80/90 pour piloter de façon centralisée et par plages horaires, les thermostats des systèmes de chauffage.

A la suite d'une concertation entre les grandes marques françaises d'appareils de chauffage, cette technologie est devenue un "standard de marché" pour les logements neufs construits à partir de 1995.

À l’aube des années 2000, la norme RT2000, rend sa présence obligatoire (par la réception de 4 ordres de contrôle) dans les logements neuf.

Peut de temps après, le protocole d'origine à 4 ordres évoluera pour un contrôle à 6 ordres, les deux dernier n'étant eux, pas obligatoire.

Le Fil Pilote permet ainsi, d'adapter au mieux, la production de chaleur, au moment d'occupation du logement. Une économie d'énergie d'environ 20% étant alors généralement constaté.

## Mais alors ? Comment ça fonctionne ?
Le principe est simple : Par un fil dédié à cet usage, les radiateurs électriques, reçoivent sous forme de signaux électriques de faible intensité, des ordres simples pour contrôler leur état.

La régulation et la mesure de température reste cependant toujours réalisée par le thermostat de chaque appareil. 
- Fil pilote 4 ordres : Confort, éco, hors gel, arrêt
- Fil pilote 6 ordres (protocole défini par le GIFAM) : Confort, confort -1°C, confort -2°C, éco, hors gel, arrêt

> [!NOTE]
> ### La norme "Fil Pilote" :
> - Les ordres sont générés et pris en compte par rapport au neutre
> - Signaux électriques (tension efficace) : 230 volts, +115 volts, -115 volts / 0,1 Ampère max
> - Le standard GIFAM encadre l'impédance d'entrée des récepteurs entre 100k et 500 kilo ohms, ce qui permet de relier de nombreux appareils de chauffage sur la même ligne. Souvent de 10 à 20 selon les caractéristiques du matériel émetteur. Par exemple, un programmateur pouvant délivrer 30 mA peut commander environ 15 thermostats d'impédance 200 K ohms.
> - Les signaux "confort -1°C" et "confort -2°C" correspondent à des périodes de présence du 230 volts alternatifs de 3 et 7 secondes espacées de périodes d'absence de signal d'environ 5 minutes. Pour des raisons techniques, la prise en compte de ces ordres peut demander un délai de 5 minutes. Quand un récepteur 4 ordres reçoit ces ordres spéciaux, il les ignore et reste en mode confort.
>
>   - __Confort :__ température de consigne en usage normal réglable de 7 à 30 °C par l'utilisateur
>   - __Eco ou réduit :__ température de confort abaissée de 3,5°C
>   - __Hors gel :__ régulation réglée sur 7 à 8°C
>   - __Arrêt :__ mise à l'arrêt de l'appareil (ou délestage)



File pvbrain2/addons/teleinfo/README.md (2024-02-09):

### Le mode standard du compteur Linky permet de récupérer des informations plus nombreuses et précises que le mode historique :

- La puissance instantanée est précise à 1W près en mode standard, au lieu de 10W en mode historique.
- Les utilisateurs équipés de panneaux photovoltaïques en autoconsommation / ré-injection peuvent visualiser leur puissance injectée dans le réseau grâce au mode standard. 
En mode historique, une puissance injectée dans le réseau est affichée à 0W.

Pour savoir si votre compteur Linky est en mode historique ou standard, faites défiler l'affichage sur votre compteur. 
L'un des écrans affichera soit `HISTORIQUE MODE TIC`, soit `STANDARD MODE TIC`.

Pour passer son compteur Linky du mode __historique__ au mode __standard__, il faut appeler votre Fournisseur d'Electricité, 
et demander le passage de votre compteur Linky en mode standard, en précisant qu’il s’agit de la prestation F185 auprès d'Enedis. 
Cette opération est gratuite et en général, le changement est effectué dans les 24 heures ouvrées.

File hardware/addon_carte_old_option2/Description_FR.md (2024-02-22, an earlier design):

### Alimentation:
- Une entree Alimentation 5v a connecter sur la carte mere.
- Un convertisseur 5v/ 3.3v pour avoir un peu de puissance (Pzem, Relais, ect...)
- Le 3.3v de l'ESP est separe et mis a disposition des entrees/sorties analogiques. (comme Pince DC et AC) 

### Les 3 sortie UART sont dispos sur bornier
- une des entrees a l'option convertisseur RS323/ TTL (UART0) 
- 3 connecteurs PZEM + une sortie sur bornier (UART2) 
- une des entree a l'option Linky (UART3) mais dispo aussi sur bornier sans l'option

### Une carte PCF8075 pour 16 sortie en bus I2c
- Possibilite de fixer une carte (4) Relais sur cette carte.
- 2 sorties supplementaire bus I2c sur borniers

### Options pour developpement future: 
- Deux sorties Sondes Dallas
- une sortie capteur dht22
- Une entree Pince DC (J'ai ajoute un filtre RC suite a l'experience du routeur solaire).
- Deux entrees Pince AC
- Toutes les GPIOs utilisables sont sorties sur borniers de facon a pouvoir faire evoluer au maximum.

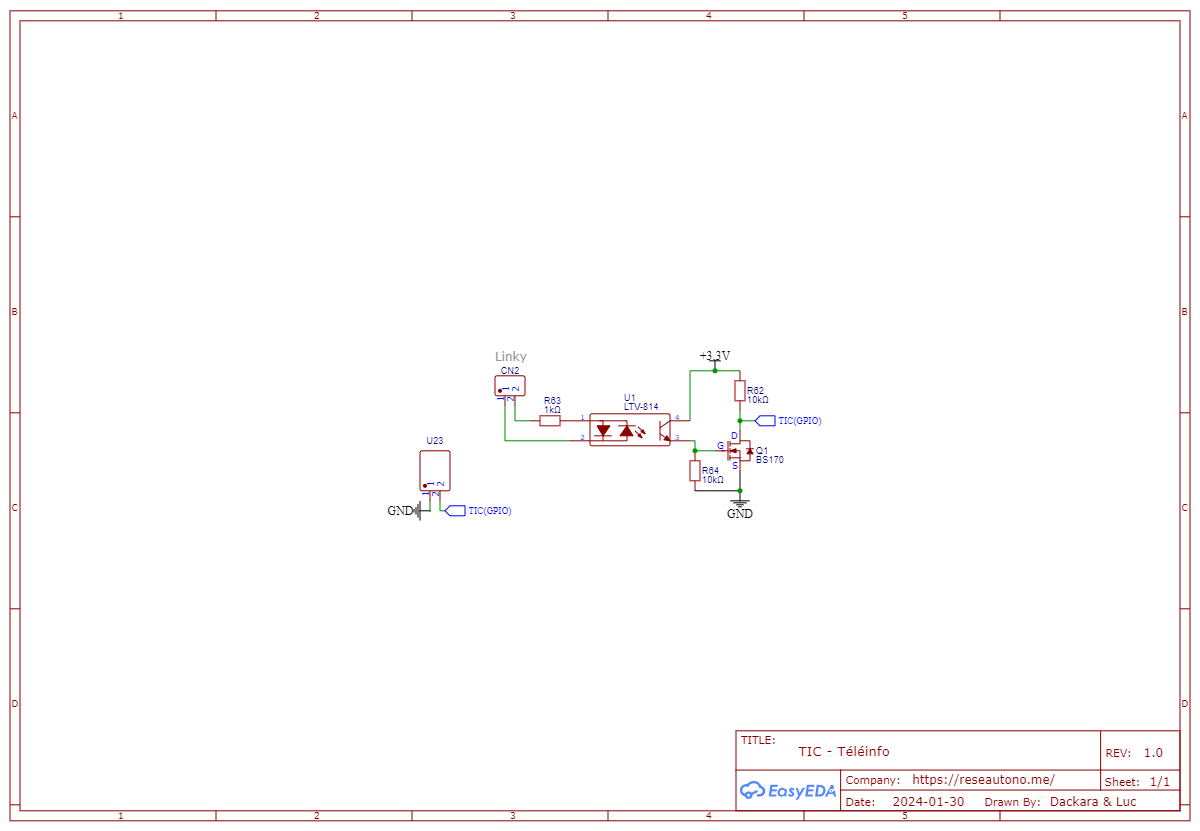
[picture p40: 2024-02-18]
hardware/addon_carte_fil_pilote/fil_pilote_schematic_tic.png

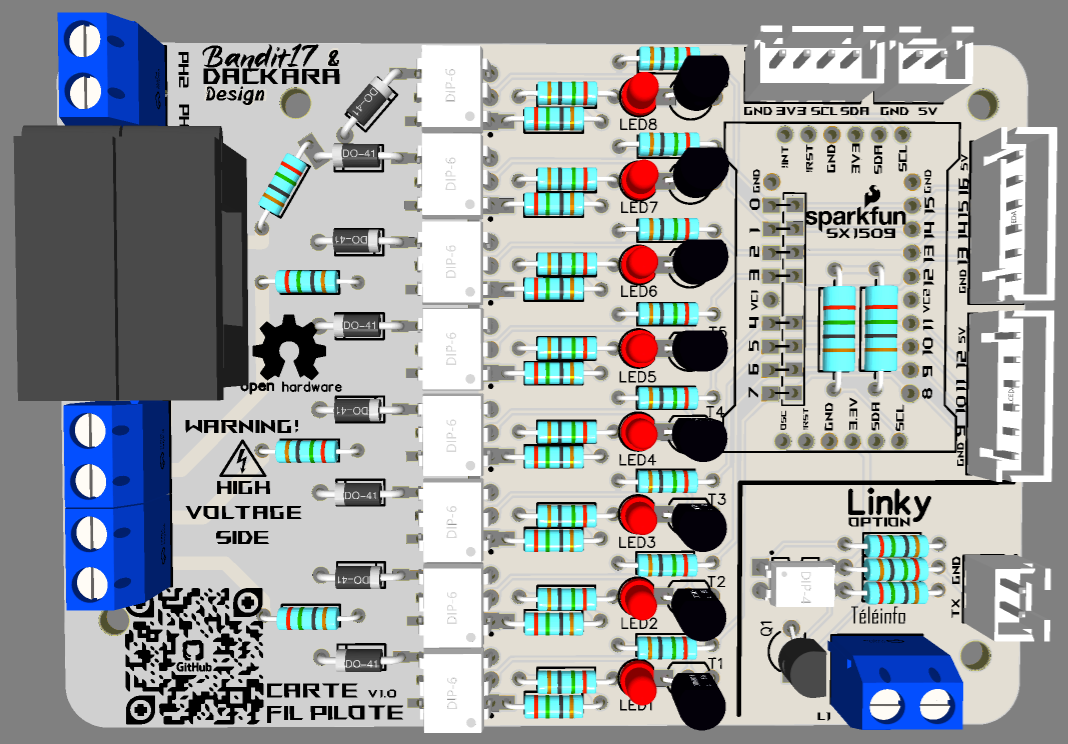
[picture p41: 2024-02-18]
hardware/addon_carte_fil_pilote/fil_pilote_v1.0_3d_view.png

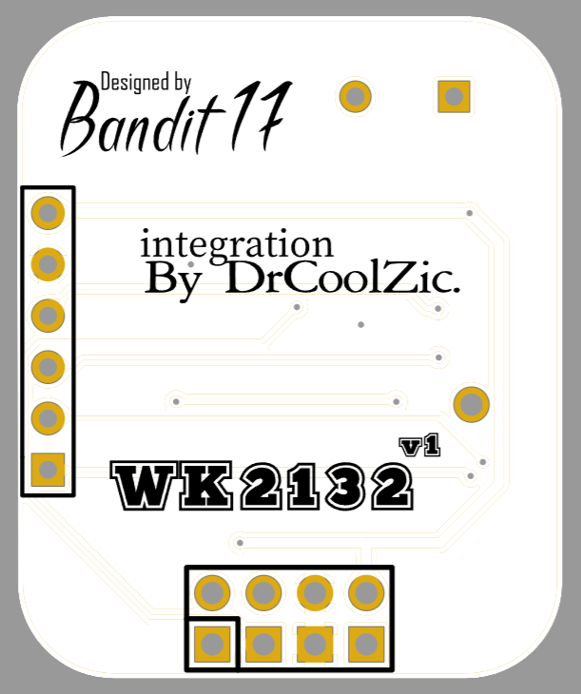
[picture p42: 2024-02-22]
hardware/module_wk_2132/wk2132_back.png

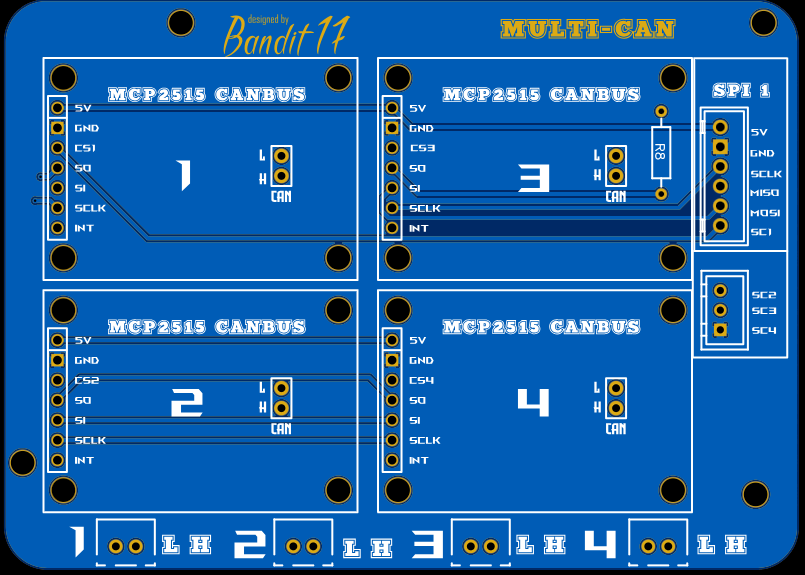
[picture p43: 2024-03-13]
hardware/addon_MULTI-CAN/MULTICAN front.PNG

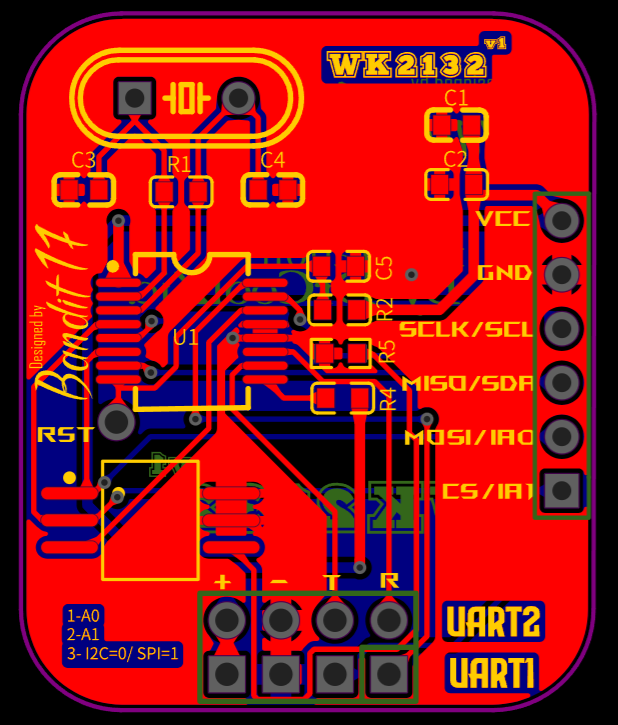
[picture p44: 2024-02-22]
hardware/module_wk_2132/wk2132_circuit.png

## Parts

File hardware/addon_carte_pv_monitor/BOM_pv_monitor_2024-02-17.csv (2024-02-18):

Name | Designator | Footprint | Quantity | Manufacturer Part | Manufacturer | Supplier Part | link
PZ254V-11-02P | Address_Change,Shunt | HDR-TH_2P-P2.54-V-M | 6 | PZ254V-11-02P | XFCN(兴飞) | C492401 | https://www.lcsc.com/product-detail/C492401.html
X6511WV-04H-C30D60 | H1,H4,H5,H6 | HDR-TH_4P-P2.54-V-M | 4 | X6511WV-04H-C30D60 | XKB Connectivity(中国星坤) | C706876 | https://www.lcsc.com/product-detail/C706876.html
CONN-TH_B2B-XH-A-LF-SN | U22 | CONN-TH_B2B-XH-A-LF-SN | 1 | B2B-XH-A(LF)(SN) | JST | C158012 | https://www.lcsc.com/product-detail/C158012.html
B4B-XH-AM(LF)(SN) | U23,U4 | CONN-TH_B4B-XH-AM-LF-SN | 2 | B4B-XH-AM(LF)(SN) | JST | C161871 | https://www.lcsc.com/product-detail/C161871.html
100uF | C1,C2 | CAP-TH_BD5.0-P2.00-D0.8-FD | 2 | SPZ1AM101D07000R | AISHI(艾华集团) | C122609 | https://www.lcsc.com/product-detail/C122609.html
Fuse transparent seat | F1,F2 | FUSE-TH_L24.5-W9.8-P22.5 | 2 | 保险丝透明座 | xcfuse(旭程) | C58066 | https://www.lcsc.com/product-detail/C58066.html
10kΩ | R1,R3 | RES-TH_BD4.5-L11.0-P15.00-D0.7 | 2 | RN 2WS 10K F T/B A1 | Tyohm(幸亚电阻) | C433623 | https://www.lcsc.com/product-detail/C433623.html
1MΩ | R2,R4 | RES-TH_BD4.5-L11.0-P15.00-D0.8 | 2 | RN 2WS 1M F T/B A1 | Tyohm(幸亚电阻) | C433621 | https://www.lcsc.com/product-detail/C433621.html
DBT50G-9.5-2P | U1,U2 | CONN-TH_2P-P9.50_DBT50G-9.5-2P | 2 | DBT50G-9.5-2P | DIBO(地博电气) | C395958 | https://www.lcsc.com/product-detail/C395958.html
U-F-M5DD-W-L | USB1 | MICRO-USB-SMD_MICRO-USB-18 | 1 | U-F-M5DD-W-L | 韩国韩荣 | C145792 | https://www.lcsc.com/product-detail/C145792.html
PWRM-TH_BXXXXS-1WR3 | U3 | PWRM-TH_BXXXXS-1WR3 | 1 | B0303S-1WR2 | DEXU(德旭电子) | C909803 | https://www.lcsc.com/product-detail/C909803.html
ADAFRUIT_ADS1115_16BIT | A1 | PCB ADS115 | 1 | ADAFRUIT_ADS1115_16BIT |  |  | https://s.click.aliexpress.com/e/_DC2KI5X
isolateur i2c | ISO1540 | ISO1540 | 1 | ISO1540 |  |  | https://s.click.aliexpress.com/e/_DkmAcod

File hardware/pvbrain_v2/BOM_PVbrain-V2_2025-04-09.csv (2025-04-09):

ID | Name | Designator | Footprint | Quantity | Manufacturer Part | Manufacturer | Supplier | Supplier Part | Price
1 | PZ254V-11-04P_C2691448 | H81,H84,H87,H90 | HDR-TH_4P-P2.54-V-M | 4 | 2.54-1*4P母 | BOOMELE(博穆精密) | LCSC | C2718488 | 0.047
2 | HDR-TH_4P-P2.54-V-M | U187,U261,U262,U263 | HDR-TH_4P-P2.54-V-M | 4 | 2.54-1*4P母 | BOOMELE(博穆精密) | LCSC | C2718488 | 0.047
3 | HDR-TH_3P-P2.54-V-M-1 | H85,H60,H80,H88,H91,H92,H93,H94 | HDR-TH_3P-P2.54-V-M-1 | 8 | CS-1165SDIG-1*3 | CST(永丰盈) | LCSC | C2886705 | 0.064
4 | HDR-M-2.54_1x6 | J7,J6 | HDR-M-2.54_1X6 | 2 |  |  | LCSC | C190819 | 0.032
5 | HDR-TH_8P-P2.54-V-M-R2-C4-S2.54 | U244,U243,U240,U239 | HDR-TH_8P-P2.54-V-M-R2-C4-S2.54 | 4 | ZX-PZ2.54-2-4PZZ | Megastar(兆星) | LCSC | C7501275 | 0.043
6 | HDR-TH_2P-P2.54-V-M-1 | H99,H100,H101,H102,H103,H104,H105,H106,H98,H8,H36,H35,H34,H33,H9,H37,H70,H69,H68 | HDR-TH_2P-P2.54-V-M-1 | 19 | 68000-102HLF | Amphenol | LCSC | C168673 | 0.189
7 | HDR-TH_3P-P2.54-V-M-1 | H5,H25,H26,H27,H28,H29,H30,H31,H32,H52,H53,H54,H55,H56,H57,H58,H64,H82,H83,H86,H89,H97,H107 | HDR-TH_3P-P2.54-V-M-1 | 23 | 2.54-1*3P针 | BOOMELE(博穆精密) | LCSC | C49257 | 0.016
8 | RES-TH_BD2.3-L6.5-P10.50-D0.5 | R29 | RES-TH_BD2.3-L6.5-P10.50-D0.5 | 1 | MF1/4W-4.7KΩ±1% T | CCO(千志电子) | LCSC | C119339 | 0.011
9 | CONN-TH_B4B-PH-K-S | U252,U255,U258,U229 | CONN-TH_B4B-PH-K-S | 4 | B4B-PH-K-S(LF)(SN) | JST | LCSC | C131334 | 0.036
10 | 68000-102HLF | H96 | HDR-TH_2P-P2.54-V-M-1 | 1 | 2.54-1*2P母 | BOOMELE(博穆精密) | LCSC | C49661 | 0.038
11 | 68000-102HLF | H95,H6 | HDR-TH_2P-P2.54-V-M-1 | 2 | 68000-102HLF | Amphenol ICC | LCSC | C168673 | 0.189
12 | TJA1051 MODULE COPY | U28 | TJA1051 MODULE COPY | 1 | TJA1051 | CJMCU | CJMCU
13 | CONN-TH_B4B-XH-A-LF-SN | U1,U3,U4,U5,U6,U7,U14,U34,U36,U40,U136,U137,U145,U146,U202,U264 | CONN-TH_B4B-XH-A-LF-SN | 16 | B4B-XH-A(LF)(SN) | JST | LCSC | C144395 | 0.049
14 | CONN-TH_3P-P2.50_HC-XH-3A-G | U139,U140,U141,U65,U64,U63,U214,U216,U215,U235 | CONN-TH_3P-P2.50_HC-XH-3A-G | 10 | HC-XH-3A-G | HCTL(华灿天禄) | LCSC | C5341202 | 0.028
15 | 470 | R4,R5 | AXIAL-0.3 | 2 | MFR0W4F4700A50 | UNI-ROYAL(厚声) | LCSC | C58592 | 0.01
16 | My_BME280 | U138 | MY_BME280 | 1 |  |  |  | C40877 | 0.07
17 | CAP-TH_BD6.3-P2.50-D1.0-FD | C2,C1 | CAP-TH_BD6.3-P2.50-D1.0-FD | 2 | SPZ1VM101E08000R | AISHI | LCSC | C122240 | 0.107
18 | DC-IN-TH_DC-005-5A-2.5 | PWR12V | DC-IN-TH_DC-005-5A-2.5 | 1 | DC-005-5A-2.5 | XKB Enterprise | LCSC | C381115 | 0.241
19 | 4.7K | R3 | RES-TH_BD3.3-L9.0-P13.00-D0.6 | 1 | RN1/2W4.7KΩFT/BA1 | TyoHM | LCSC | C385631 | 0.019
20 | CONN-TH_6P-P2.50_B6B-XH-A-LF-SN | U15,U16,U17,U18,U19,U22,U23,U24,U158,U218 | CONN-TH_6P-P2.50_B6B-XH-A-LF-SN | 10 | B6B-XH-A(LF)(SN) | JST | LCSC | C144397 | 0.068
21 | Fuse transparent seat | F3,F2,F1 | FUSE-TH_L24.5-W9.8-P22.5 | 3 | 保险丝透明座 | xcfuse(旭程) | LCSC | C58066 | 0.209
22 | HDR-TH_1P-P2.54-V-M | P5,P6,P7,P8,P4,P3,P2,P1 | HDR-TH_1P-P2.54-V-M | 8 | PH-00676 | Liansheng(连盛) | LCSC | C2685179 | 0.021
23 | CONN-TH_XY118-5.0-2P | U48,U213 | CONN-TH_XY118-5.0-2P | 2 | XY118-5.0-2P | Ningbo Xinlaiya Elec. | LCSC | C784922 | 0.224
24 | HDR-TH_22P-P2.54-V-M | U20,U21 | HDR-TH_22P-P2.54-V-M | 2 | X6511WV-22H-C30D60 | XKB Connectivity(中国星坤) | LCSC | C725954 | 0.367
25 | HDR-TH_8P-P2.54-V-M-R2-C4-S2.54 | U37,U39,U10,U157 | HDR-TH_8P-P2.54-V-M-R2-C4-S2.54 | 4 | 210S-2*4P L=11.6MMGold-plated black | Ckmtw | LCSC | C124386 | 0.055
26 | RES-TH_BD2.2-L6.5-P10.50-D0.6 | R1,R2 | RES-TH_BD2.2-L6.5-P10.50-D0.6 | 2 | MFR50SJT-52-4K7 | YAGEO | LCSC | C176641 | 0.015
27 | HDR-TH_1P-P2.54-V-M | P21,P20,P19,P18,P17 | HDR-TH_1P-P2.54-V-M | 5 | DZ254R-11-01-63 | DEALON(德艺隆) | LCSC | C2998932 | 0.007
28 | USB-A-TH_907-422A1051Y10210 | U9 | USB-A-TH_907-422A1051Y10210 | 1 | 907-422A1111Y10210 | 精拓金 | LCSC | C708953 | 0.282
29 | RJ45-TH_R-RJ45S08P-B000 | U13,U164,U163,U162,U165,U212 | RJ45-TH_R-RJ45S08P-B000 | 6 | R-RJ45S08P-B000 | Ckmtw(灿科盟) | LCSC | C386763 | 0.422
30 | HDR-TH_6P-P2.54-V-F | H3,H38,H44,H41,H40,H47 | HDR-TH_6P-P2.54-V-F | 6 | PM254V-11-06-H85 | XFCN(兴飞) | LCSC | C2832269 | 0.074
31 | HDR-TH_10P-P2.54-V-F | H4 | HDR-TH_10P-P2.54-V-F | 1 |  |  |  | C2905418 | 0.1
32 | HDR-TH_10P-P2.54-V-F | H43,H42,H39 | HDR-TH_10P-P2.54-V-F | 3 | KH-2.54FH-1X10P-H8.5 | kinghelm(金航标) | LCSC | C2905418 | 0.1
33 | HDR-TH_8P-P2.54-V-M-R2-C4-S2.54 | U171,U170,U169,U168,U167,U166,U11,U184,U183,U182,U181,U180,U172,U211 | HDR-TH_8P-P2.54-V-M-R2-C4-S2.54 | 14 | ZX-PZ2.54-2-4PZZ | Megastar(兆星) | LCSC | C124386 | 0.055
34 | HDR-TH_8P-P2.54-V-F-R2-C4-S2.54 | H51,H67,H66,H65 | HDR-TH_8P-P2.54-V-F-R2-C4-S2.54 | 4 | ZX-PM2.54-2-4PY | Megastar(兆星) | LCSC | C7499340 | 0.125
35 | HDR-TH_22P-P2.54-V-F | U26,U25 | HDR-TH_22P-P2.54-V-F | 2 | CS-1165SDIG-1*22 | CST(永丰盈) | LCSC | C2886702 | 0.136
36 | HDR-TH_4P-P2.54-V-M | U179,U178,U177,U176,U175,U174,U173,U12 | HDR-TH_4P-P2.54-V-M | 8 | PZ254V-11-04P | XFCN(兴飞) | LCSC | C2691448 | 0.02
37 | LED-TH_3P-BD3.9-P2.54-R-FD | LED1 | LED-TH_3P-BD3.9-P2.54-R-FD | 1 | XL-A324SURUBW | XINGLIGHT(成兴光) | LCSC | C2895559 | 0.04
38 | HDR-TH_7P-P2.54-V-F | H11 | HDR-TH_7P-P2.54-V-F | 1 | PM254V-11-07-H85 | XFCN(兴飞) | LCSC | C2832270 | 0.085
39 | HC-49US_L11.5-W4.5-P4.88 | U242,U236 | HC-49US_L11.5-W4.5-P4.88 | 2 | X49SD147456MSD2SC | YXC(扬兴晶振) | LCSC | C11233 | 0.081
40 | SW-SMD_DSHP03TS-S | SW7,SW6 | SW-SMD_DSHP03TS-S | 2 | DSHP03TS-S | XKB Connectivity(中国星坤) | LCSC | C319051 | 0.591
41 | 4.7K | R28,R21 | R0603 | 2 | RMC06034.7k5%N | Tyohm | LCSC | C269694 | 0.003
42 | 100nF | C45,C32 | C0603 | 2 | 0603B104K500NT | FH | LCSC | C30926 | 0.002
43 | 10K | R27,R22 | C0603 | 2 | RC0603FR-0710KL | YAGEO | LCSC | C98220 | 0.001
44 | 1uF | C44,C41,C36,C33 | C0603 | 4 | CL10A105KA8NNNC | SAMSUNG | LCSC | C5673 | 0.004
45 | 10nF | C43,C40,C37,C34 | C0603 | 4 | CC0603KRX7R9BB103 | YAGEO | LCSC | C100042 | 0.002
46 | 5.1k | R26,R23 | C0603 | 2 | 0603WAF5101T5E | UniOhm | LCSC | C23186 | 0.001
47 | 20pF | C42,C39,C38,C35 | C0603 | 4 | CC0603JRNPO9BN200 | YAGEO | LCSC | C105621 | 0.003
48 | 1MΩ | R25,R24 | C0603 | 2 | 0603WAF1004T5E | UniOhm | LCSC | C22935 | 0.001
49 | WK2168-IQPG | U241,U237 | QFP-48_L7.0-W7.0-P0.50-LS9.0-BL | 2 | WK2168-IQPG | 成都为开 | LCSC | C401041 | 5.424
50 | HDR-TH_8P-P2.54-V-M | U250,U249 | HDR-TH_8P-P2.54-V-M | 2 | PZ254V-11-08P | XFCN(兴飞) | LCSC | C492407 | 0.045
51 | PWRM-TH_BXXXXS-1WR3 | U31,U260,U257,U254 | PWRM-TH_BXXXXS-1WR3 | 4 | B0303S-1WR2 | DEXU(德旭电子) | LCSC | C909803 | 0.979
52 | SOIC-8_L4.9-W3.9-P1.27-LS6.0-BL | U228,U259,U256,U253 | SOIC-8_L4.9-W3.9-P1.27-LS6.0-BL | 4 | π122M31 | 2Pai Semi(荣湃) | LCSC | C471594 | 0.453
53 | C0805 | C23,C58,C56,C54 | C0805 | 4 | CL21B225KAFNNNE | SAMSUNG(三星) | LCSC | C19110 | 0.012
54 | C0805 | C24,C57,C55,C53 | C0805 | 4 | CS2012X7R475K350NRE | SAMWHA(三和) | LCSC | C560882 | 0.032
55 | HDR-TH_4P-P2.00-V-M-R2-C2-S2.00-3 | U27 | HDR-TH_4P-P2.00-V-M-R2-C2-S2.00-3 | 1 | 2005WV-2x2P | HanElectricity(瀚源) | LCSC | C6837602 | 0.021

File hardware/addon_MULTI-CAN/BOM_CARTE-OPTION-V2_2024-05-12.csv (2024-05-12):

ID | Name | Designator | Footprint | Quantity | Manufacturer Part | Manufacturer | Supplier | Supplier Part | Price | Value
1 | CONN-TH_B2B-XH-A-LF-SN | U3,U4,U5,U6 | CONN-TH_B2B-XH-A-LF-SN | 4 | B2B-XH-A(LF)(SN) | JST | LCSC | C158012 | 0.03
2 | HDR-TH_7P-P2.54-V-F | H11,H97,H99,H101 | HDR-TH_7P-P2.54-V-F | 4 | PM254V-11-07-H85 | XFCN(兴飞) | LCSC | C2832270 | 0.128
3 | 68000-102HLF | H96,H98,H100,H102 | HDR-TH_2P-P2.54-V-M-1 | 4 | 2.54-1*2P母 | BOOMELE(博穆精密) | LCSC | C49661 | 0.034
4 | RES-TH_BD2.3-L6.5-P10.50-D0.5 | R8 | RES-TH_BD2.3-L6.5-P10.50-D0.5 | 1 | MF1/4W-4.7KΩ±1% T | CCO(千志电子) | LCSC | C119339 | 0.012 | 4.7kΩ
5 | CONN-TH_6P-P2.50_B6B-XH-A-LF-SN | U158 | CONN-TH_6P-P2.50_B6B-XH-A-LF-SN | 1 | B6B-XH-A(LF)(SN) | JST | LCSC | C144397 | 0.081
6 | CONN-TH_3P-P2.50_HC-XH-3A-G | U214 | CONN-TH_3P-P2.50_HC-XH-3A-G | 1 | HC-XH-3A-G | HCTL(华灿天禄) | LCSC | C5341202 | 0.024

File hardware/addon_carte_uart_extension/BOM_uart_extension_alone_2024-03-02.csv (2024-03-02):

Name | Designator | Quantity | Manufacturer Part | Manufacturer | Supplier Part | Price
HDR-TH_4P-P2.54-V-M | U176,U173,U175,U174 | 4 | PZ254V-11-04P | XFCN(兴飞) | C2691448 | 0.023
HDR-TH_3P-P2.54-V-M-1 | H54,H5,H53,H52,H57,H56 | 6 | 2.54-1*3P针 | BOOMELE(博穆精密) | C49257 | 0.012
HDR-TH_8P-P2.54-V-M-R2-C4-S2.54 | U166,U169,U168,U167 | 4 | ZX-PZ2.54-2-4PZZ | Megastar(兆星) | C124386 | 0.054
HDR-TH_2P-P2.54-V-M-1 | H55,H36 | 2 | 68000-102HLF | Amphenol | C168673 | 0.169
CONN-TH_B4B-XH-A-LF-SN | U136,U137,U177,U178,U180,U181 | 6 | B4B-XH-A(LF)(SN) | JST | C144395 | 0.052
HDR-TH_3P-P2.54-V-M-1 | H28,H27,H25,H26 | 4 | 68000-103HLF | Amphenol ICC | C168677 | 0.214
CONN-TH_6P-P2.50_B6B-XH-A-LF-SN | U227 | 1 | B6B-XH-A(LF)(SN) | JST | C144397 | 0.088
WK2168 | U2 | 1
HDR-TH_8P-P2.54-V-M-R2-C4-S2.54 | U230 | 1 | 210S-2*4P L=11.6MMGold-plated black | Ckmtw | C124386 | 0.054
HDR-TH_6P-P2.54-V-M-R2-C3-S2.54 | U1 | 1 | PZ254V-12-6P | XFCN(兴飞) | C492420 | 0.033

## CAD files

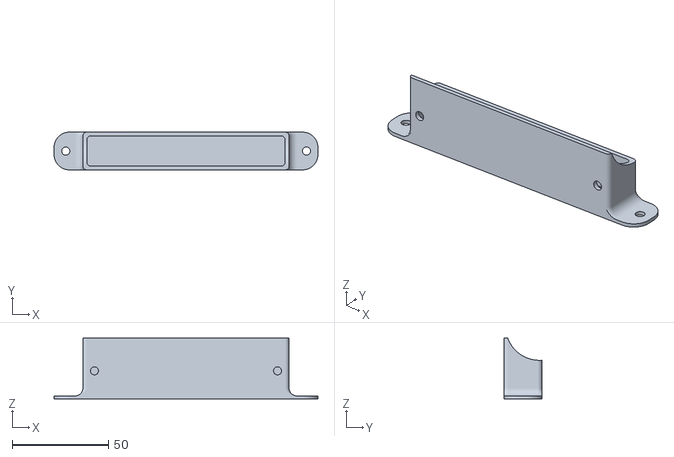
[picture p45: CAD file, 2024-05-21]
hardware/printable_3d_files/JKBMS_Vertical_Support/Support_JKBMS.stl
137.0 x 19.6 x 31.6

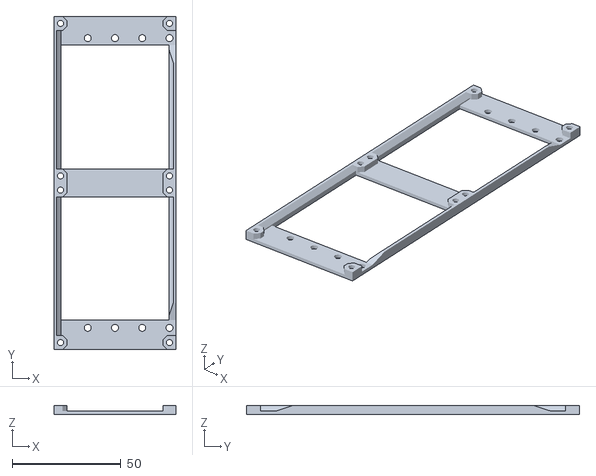
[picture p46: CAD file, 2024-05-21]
hardware/printable_3d_files/Platine 2x_4Relay_(50mm)_for_8Opto_card.stl
56.0 x 153.0 x 4.20

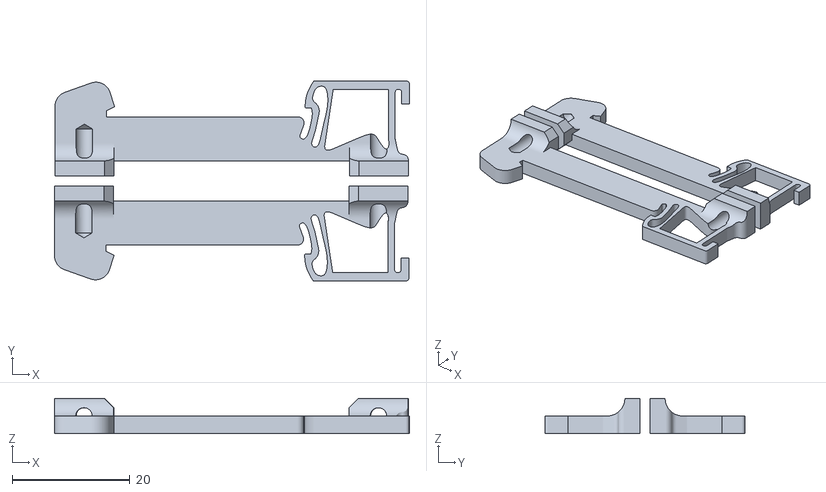
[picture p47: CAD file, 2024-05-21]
hardware/printable_3d_files/PvBrain2_Opto_relay_DIN_Mount_50mm_x2.stl
60.3 x 33.9 x 6.00

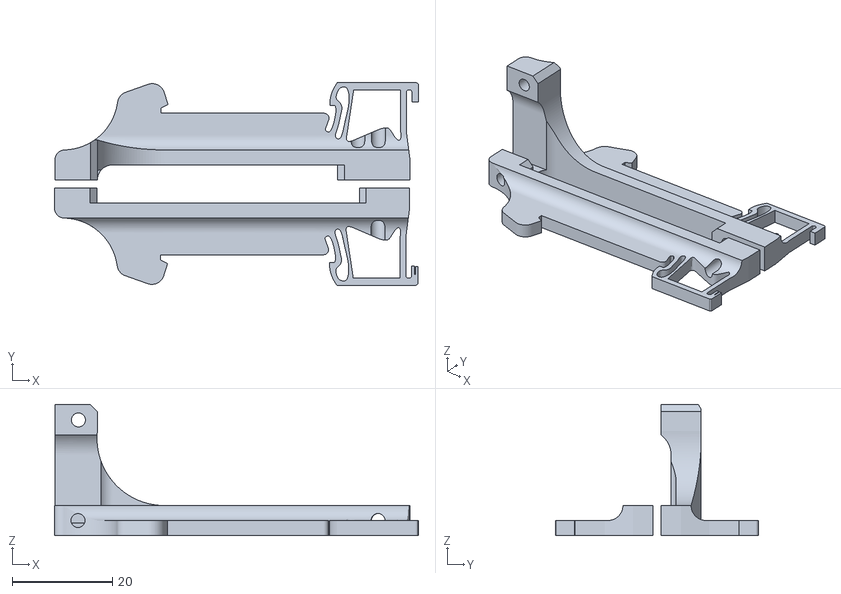
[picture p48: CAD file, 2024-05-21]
hardware/printable_3d_files/PvBrain2_AddonCard_DIN_Mount_v2.stl
72.8 x 40.5 x 26.2

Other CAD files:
hardware/printable_3d_files/PvBrain2_Relay_DIN_Mount_45mm_x2.stl

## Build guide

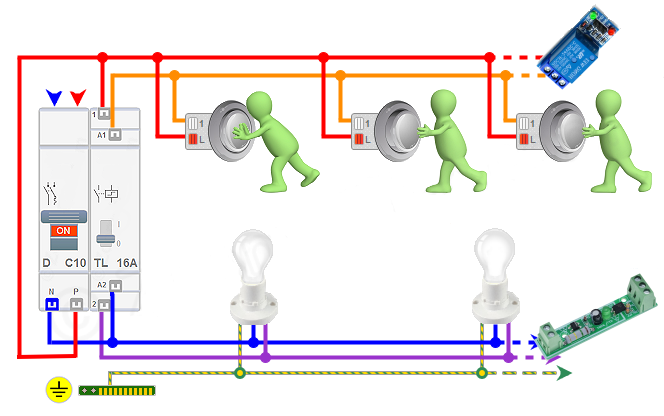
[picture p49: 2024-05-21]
pvbrain2/environmental/light/teleruptor/pictures/how_install.png

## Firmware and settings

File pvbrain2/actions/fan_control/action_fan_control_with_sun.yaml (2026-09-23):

sun:
  latitude: !secret esphome_lat
  longitude: !secret esphome_long
  id: my_sun
  
time:
  - platform: homeassistant #sntp
    id: !extend my_time

switch:
  - platform: template
    name: ${name}_${fan_control_name}_automatic_control
    id: ${fan_control_name}_automatic_control
    optimistic: true
    restore_mode: ALWAYS_ON 

# binary_sensor:
  - platform: template
    name: ${name}_${fan_control_name}_after_sunrise
    id: ${fan_control_name}_after_sunrise
    optimistic: true
    on_turn_on:
      then:
        - lambda: |-
            if( (id(${fan_control_name}_after_sunrise).state) && (id(${fan_control_name}_before_sunset).state) ){
              id(${fan_control_name}_working).publish_state(true);
            }
            else{
              id(${fan_control_name}_working).publish_state(false);
            }
    on_turn_off:
      then:
        - lambda: |-
            if( (id(${fan_control_name}_after_sunrise).state) && (id(${fan_control_name}_before_sunset).state) ){
              id(${fan_control_name}_working).publish_state(true);
            }
            else{
              id(${fan_control_name}_working).publish_state(false);
            }        
    
  - platform: template
    name: ${name}_${fan_control_name}_before_sunset
    id: ${fan_control_name}_before_sunset
    optimistic: true
    on_turn_on:
      then:
        - lambda: |-
            if( (id(${fan_control_name}_after_sunrise).state) && (id(${fan_control_name}_before_sunset).state) ){
              id(${fan_control_name}_working).publish_state(true);
            }
            else{
              id(${fan_control_name}_working).publish_state(false);
            }
    on_turn_off:
      then:
        - lambda: |-
            if( (id(${fan_control_name}_after_sunrise).state) && (id(${fan_control_name}_before_sunset).state) ){
              id(${fan_control_name}_working).publish_state(true);
            }
            else{
              id(${fan_control_name}_working).publish_state(false);
            }
    
  - platform: template
    name: ${name}_${fan_control_name}_working
    id: ${fan_control_name}_working
    optimistic: true
    on_turn_on:
      then:
        - lambda: |-
            if(id(${fan_control_name}_automatic_control).state){
              if(id(${fan_control_name}_working).state){
                /*
                if(!id(${fan_control_relay0_id}).state){
                  id(${fan_control_relay0_id}).turn_on();
                }
                */
                if(!id(${fan_control_relay1_id}).state){
                  id(${fan_control_relay1_id}).turn_on();
                }
                /*
                if(!id(${fan_control_relay2_id}).state){
                  id(${fan_control_relay2_id}).turn_on();
                }
                */
                if(!id(${fan_control_relay3_id}).state){
                  id(${fan_control_relay3_id}).turn_on();
                }
                id(${fan_control_dc_dimmer1_id}_output).set_level(id(${fan_control_name}_${fan_control_dc_dimmer1_id}_max).state*0.01);
                id(${fan_control_dc_dimmer1_id}_command).make_call().set_speed(id(${fan_control_name}_${fan_control_dc_dimmer1_id}_max).state).perform();
                id(${fan_control_dc_dimmer1_id}_command).turn_on().perform();
                
                id(${fan_control_dc_dimmer2_id}_output).set_level(id(${fan_control_name}_${fan_control_dc_dimmer2_id}_max).state*0.01);
                id(${fan_control_dc_dimmer2_id}_command).make_call().set_speed(id(${fan_control_name}_${fan_control_dc_dimmer2_id}_max).state).perform();
                id(${fan_control_dc_dimmer2_id}_command).turn_on().perform();
                
                id(${fan_control_dc_dimmer3_id}_output).set_level(id(${fan_control_name}_${fan_control_dc_dimmer3_id}_max).state*0.01);
                id(${fan_control_dc_dimmer3_id}_command).make_call().set_speed(id(${fan_control_name}_${fan_control_dc_dimmer3_id}_max).state).perform();
                id(${fan_control_dc_dimmer3_id}_command).turn_on().perform();
                
                id(${fan_control_dc_dimmer4_id}_output).set_level(id(${fan_control_name}_${fan_control_dc_dimmer4_id}_max).state*0.01);
                id(${fan_control_dc_dimmer4_id}_command).make_call().set_speed(id(${fan_control_name}_${fan_control_dc_dimmer4_id}_max).state).perform();
                id(${fan_control_dc_dimmer4_id}_command).turn_on().perform();      
               }
            }               
    on_turn_off:
      then:
        - lambda: |-
            if(id(${fan_control_name}_automatic_control).state){
              /*
              if(!id(${fan_control_relay0_id}).state){
                  id(${fan_control_relay0_id}).turn_on();
                }
              */  
              if(!id(${fan_control_relay1_id}).state){
                  id(${fan_control_relay1_id}).turn_on();
                }
              /*  
              if(!id(${fan_control_relay2_id}).state){
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

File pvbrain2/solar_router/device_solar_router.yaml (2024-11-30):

external_components:
  - source: "github://SeByDocKy/myESPhome/"
    components: [solarpid]
    refresh: 0s  
    
number:
    
  - platform: template
    name: ${name}_${solar_router_name}_setpoint
    id: ${solar_router_name}_setpoint
    optimistic: true
    unit_of_measurement: 'A'
    icon: mdi:current-dc
    min_value: -80
    max_value: 80
    step: 0.1
    mode: 'slider'
    initial_value: 0
    restore_value: true
    on_value:
       then:
         - solarpid.set_point: 
            id: ${solar_router_id}
            new_setpoint: !lambda |-
              return (float(id(${solar_router_name}_setpoint).state));
           
  - platform: template
    name: ${name}_${solar_router_name}_setkp
    id: ${solar_router_name}_setkp
    optimistic: true
    min_value: 0.0
    max_value: 10.0
    step: 0.1
    mode: 'slider'
    initial_value: 3.0
    restore_value: true
    on_value:
       then:
         - solarpid.set_kp: 
            id: ${solar_router_id}
            new_kp: !lambda |-
              return (float(id(${solar_router_name}_setkp).state));
           
  - platform: template
    name: ${name}_${solar_router_name}_setki
    id: ${solar_router_name}_setki
    optimistic: true
    min_value: 0.0
    max_value: 0.5
    step: 0.01
    mode: 'slider'
    initial_value: 0.0
    restore_value: true
    on_value:
       then:
         - solarpid.set_ki: 
            id: ${solar_router_id}
            new_ki: !lambda |-
              return (float(id(${solar_router_name}_setki).state));
         
  - platform: template
    name: ${name}_${solar_router_name}_setkd 
    id: ${solar_router_name}_setkd
    optimistic: true
    min_value: 0.0
    max_value: 1.0
    step: 0.01
    mode: 'slider'
    initial_value: 0.0
    restore_value: true
    on_value:
       then:
         - solarpid.set_kd: 
            id: ${solar_router_id}
            new_kd: !lambda |-
              return (float(id(${solar_router_name}_setkd).state));                                   
  
  - platform: template
    name: ${name}_${solar_router_name}_setoutputmin 
    id: ${solar_router_name}_setoutputmin
    optimistic: true
    min_value: 0.0
    max_value: 1.0
    step: 0.01
    mode: 'slider'
    initial_value: 0.13
    restore_value: true
    on_value:
       then:
         - solarpid.set_output_min: 
            id: ${solar_router_id}
            new_output_min: !lambda |-
              return (float(id(${solar_router_name}_setoutputmin).state));                                   
       
  - platform: template
    name: ${name}_${solar_router_name}_setoutputmax 
    id: ${solar_router_name}_setoutputmax
    optimistic: true
    min_value: 0.0
    max_value: 1.0
    step: 0.01
    mode: 'slider'
    initial_value: 0.85
    restore_value: true
    on_value:
       then:
         - solarpid.set_output_max: 
            id: ${solar_router_id}
            new_output_max: !lambda |-
              return (float(id(${solar_router_name}_setoutputmax).state));  

  - platform: template
    name: ${name}_${solar_router_name}_setstartingbatteryvoltage 
    id: ${solar_router_name}_setstartingbatteryvoltage
    optimistic: true
    unit_of_measurement: 'V'
    icon: mdi:sine-wave
    min_value: 50.0
    max_value: 56.0
    step: 0.1
    mode: 'slider'
    initial_value: 54.0
    restore_value: true
    on_value:
       then:
         - solarpid.set_starting_battery_voltage: 
            id: ${solar_router_id}
            new_starting_battery_voltage: !lambda |-
              return (float(id(${solar_router_name}_setstartingbatteryvoltage).state));

  - platform: template
    name: ${name}_${solar_router_name}_setoutputrestart
    id: ${solar_router_name}_setoutputrestart
    optimistic: true
    min_value: 0.0
    max_value: 1.0
    step: 0.05
    mode: 'slider'
    initial_value: 0.40
    restore_value: true
    on_value:
       then:
         - solarpid.set_output_restart: 
            id: ${solar_router_id}
            new_output_restart: !lambda |-
              return (float(id(${solar_router_name}_setoutputrestart).state));                   
switch:
  - platform: template
    name: ${name}_${solar_router_name}_activation
    id: ${solar_router_name}_activation
    optimistic: true
    restore_mode: RESTORE_DEFAULT_OFF
    
  - platform: template
    name: ${name}_${solar_router_name}_manual_override
    id: ${solar_router_name}_manual_override
    optimistic: true
    restore_mode: RESTORE_DEFAULT_OFF
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

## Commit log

2024-01-04 Add first pvbrain2 code
    [device_robotdyn.yaml]
2024-01-05 - baudrate and uart_hub (I2C/SPI) more easy
2024-01-05 - add powermeter pzem004TV3
2024-01-05 - Add victron smartsolar charger
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2024-01-09 - Add esmart3 solar charger & growatt inverter
2024-01-11 - Extract light led config from base.
    Need to Update to last Esphome dev !!!!
2024-01-11 Update device_base.yaml
    Add wifi_info sensors
2024-01-14 - Added eastron SDMxxx powermeter
2024-01-14 - Fix time object into list & cosmetic changes
    [device_ats.yaml]
2024-02-07 Update README.md
    Add 3d print rail mount
2024-02-14 Update
    - Reorganization of the image and hardware sections.
    - Update README
    - Fix addon code Fil_Pilote zones 5 to 8
    [pvbrain_v2_BOM.xlsx, wk2168_BOM_2024-02-10.csv, wk2168_PickAndPlace_2024-02-10.csv]
2024-02-17 Update
    Add Gerber files, BOM and schematic
    [carte_option2_BOM_2024-02-04.xls, pv_monitor_BOM_2024-02-17.csv, pv_monitor_PickAndPlace_2024-02-17.csv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]
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2024-02-20 Update
    Add :
    - BMP280 config
    - many Gerber, BOM, PickAndPlace, Schematic...
    Update README
    [BOM_UART_Extension_with_victron_2024-02-20.csv, BOM_carte_option2_2024-02-04.xls, BOM_pv_monitor_2024-02-17.csv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]
2024-02-21 Update
    Add Gerber files for assembly complete card
    [BOM_PVbrain_V2_with_wk2168_isolator_shunt_2024-02-21.csv, PickAndPlace_PVbrain_V2_with_wk2168_isolator_shunt_2024-02-21.csv]
2024-03-02 Update
    Update of images and Gerber files for the Live of launch
    [BOM_PVbrain_V2_with_wk2168_isolator_shunt_2024-02-21.csv, BOM_PVbrain_V2_with_wk2168_isolator_shunt_2024-03-02.csv, BOM_UART_Extension_with_victron_2024-02-20.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]
2024-03-07 Update device_wk2168_spi.yaml
    fix dependances
    [device_wk2168_spi.yaml]
2024-03-07 Update device_wk2168_i2c.yaml
    fix depedances
    [device_wk2168_i2c.yaml]
2024-03-07 Update device_wk2132_i2c.yaml
    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
    [device_wk2132_i2c.yaml]
2024-03-07 Update device_wk2132_spi.yaml
    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
    [device_wk2132_spi.yaml]
2024-03-19 Update README.md
    Add link to the Google Docs (BOM file).
2024-03-23 -fix sufix to suffix in entity's name
    [device_robotdyn.yaml]
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2024-03-31 Add some hardware compilation parameters according to some ESP32 S3
2024-03-31 Try to fix ESP32 S3 N32R8V with ESP-IDF
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2024-04-06 For 32Mb ESP32 S3 model
    [large_littlefs_32MB.csv]
2024-04-07 Update INA3221 and Fixing broken code during commit [b084d51]
    Fixing broken code during commit [b084d51](https://github.com/SeByDocKy/pvbrain2/commit/b084d51b38066e9eea0d8aa352c59f3703b001b5)
    - Several updates thread_drivers broken
    - Historical and standard teleinfo broken
    - Re-addition of `parity: EVEN` and `data_bits: 7` in the `device_physical_uart.yaml` file (otherwise the teleinfo will not work)
    - Added current and power measurement of the INA3221 and moved the files to the `powermeter\dc\texas_instruments` folder
2024-04-09 Change uart_id to id to fillform final WK2168 requierements
2024-04-10 Fix uart_id => id
2024-04-10 Fix mosi GPIO 11=>6
    [device_wk2168_spi.yaml]
2024-04-10 Update device_ats.yaml
    ajout de l'option de commutation ATS avec les cellules mini
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2024-04-11 Update device_ina3221.yaml
    Fix id: missing for power_channel
2024-04-11 Update device_pylontech.yaml
    Add suffix and name in the name
2024-04-13 Update device_sx1509.yaml
    Just add address 0x70 and 0x71 in comment
2024-04-14 Update device_ina3221.yaml
    Fix INA3221
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2024-04-18 Update pvbrain2.yaml
    Broken path fort addon uart extention
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2024-04-28 Update for v1.0.1
    ## version change: v1.0.1
    - remove all '${suffix}' entry
    - add multiple images to prepare the wiki
    - add '!extend' and '!remove' exemple in the pvbrain2.yaml
    - add effects for the LEDs on the pvbrain card
    - add support for the RGB LED included on the ESP S3
    - add a switch for reboot in safe_mode and for shutdown
    - add a sensor with compiler version
    - add of select button to modify the baudrate of physical uarts when running (*in comment section)
    - add support for Rtttl buzzers
    [device_robotdyn.yaml]
2024-04-29 Removed version recommended for esp-idf (it's default) and bump arduino core lib to 2.0.15
2024-05-07 Update
    Add ID for INA3221
    Deplace light/effect/...
    Securise initial value of Fil_Pilote on re/boot
    Correct name for picture pwm_output
    Add a yaml contain a config for force esp to use max PSRAM possible (pvbrain2/base/config_force_psram.yaml)
    un-hide "hide_timestamp" for "esphomelib_version" sensor
2024-05-09 Fix scripts & time for multi-SRNE case
2024-05-10 Fix default Baudrate for SRNE (19200->9600) for UART3
2024-05-20 Sum of several PV sources (power & energy)
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2024-05-21 Update for more template
    1 263 / 5 000
    - Several 3D files
    - ~~Update of the Gerber Pv_Monitor and Clamp_Meter~~ *later, possibly this weekend... didn't have time...*
    - First version of the code for the Clamp_Meter
    - Update `config_force_psram.yaml`
    - Update `device_debug.yaml` (addition of text_sensors and variable on PSRAM size)
    - Replacement of names containing "_yesteday" by "_yeste**r**day"
    - Added `device_pwm_fan.yaml` (automatic control of the 4-wire PWM fan according to temperature probe)
    - Added `device_teleruptor.yaml` (control of a light teleruptor with feedback of its state)
    - Added the 'WLED' platform
    - Added `device_sun.yaml`
    - Added different templates:
    - bme_based (diff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
    [Platine 2x_4Relay_(50mm)_for_8Opto_card.stl, PvBrain2_AddonCard_DIN_Mount_v2.stl, PvBrain2_Opto_relay_DIN_Mount_50mm_x2.stl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]
2024-05-21 Delete hardware/printable_3d_files/README.md
    Small Readme deleted for now.
    See you later ;-)
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2024-05-25 - Add pos, neg power & energy (today, yesterday)
2024-05-25 fix today template energy sensor
2024-05-26 - remove extra ) in some text sensors....
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2024-05-31 fix battery_charging_yesterday name
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2024-06-21 Improve fan control with sun
    Now it resumes fan control whatever a reboot of the ESP
    [action_fan_control_with_sun.yaml]
2024-06-25 Update device_dallas.yaml
    modification following the change "dallas" to "one_wire"
2024-07-14 Reorganization of base YAML + new canbus devices
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2024-09-02 Update device_smartshunt.yaml
    Make discharging power a positive value
2024-09-02 Update device_jsy231.yaml
    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
2024-10-06 Add sofar TLG3 (mono) model
    [Kopia Sofar G3 Modbus.xlsx]
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2024-10-11 Fix some icons and a sensor
2024-10-11 Fix some icons, add a sensor
2024-10-19 Update pvbrain2.yaml
    add: spi data rate frequency for all wk2168
2024-10-19 Update device_base.yaml
    add led on WLED port with 2812 strip
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2024-11-01 Update device_jsy194.yaml
    Rename "yesteday" to "yesterday" with "R"
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2025-01-08 Broadcasting JK-PB settings to all BMS set to OFF by default
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2025-04-07 fix current register size
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2025-05-17 Fix deviceclass energy
2025-06-16 New `board` YAMLs for PVbrain2 Remote Packages version
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2025-06-25 Fix grid voltage register and optimize a bit more
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2025-07-30 Added `name` for `inverter_com_status` used for CANBUS and RS485
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2025-09-09 Add cp negative, power, energy and button on/off
2025-09-11 fix some unit, device_class
2025-12-23 Replace some switches with comon select
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2026-02-24 Update device_deye_nominal.yaml
    modification ${inverter_name}_battery_current pas a la bonne échelle.
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2026-03-26 Fix: inverse PWM calculation to match IEC 61851
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2026-07-17 Update device_jkbms.yaml
    WARNING 'power_tube_temperature' is deprecated, use 'mosfet_temperature' instead. Will be removed in a future release.
    WARNING 'total_battery_capacity_setting' is deprecated, use 'mosfet_temperature' instead. Will be removed in a future release.
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2026-08-20 Restore DTS6619 configuration in device_dts6619.yaml
    Restored globals, time, modbus_controller, and sensor configurations for the DTS6619 device. Added comments for testing and configuration.
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2026-09-22 Enhance sensor configuration with device and state classes
    Added device_class and state_class to sensor configuration.
2026-09-22 Fix formatting issues in device_pyr20.yaml
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2026-09-23 Fix typo in print statement
2026-09-23 Remove unused throttle settings from pvbrain2.yaml
    Removed commented-out throttle settings for powermeter and bms.
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2026-09-23 Refactor YAML structure for AC leakage sensor
2026-09-23 Comment out various environmental and charger settings
    Commented out environmental and solar charger configurations along with modbus throttle settings.
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2026-09-24 Modify total_2energies.yaml sensor configuration
    Updated sensor configuration to include state_class as total_increasing.
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2026-09-24 Modify energy sensor configuration
    Updated state class to 'total_increasing' for energy sensor.
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2026-10-01 Enhance sensor definitions in total_6powers.yaml
    Added state_class to total_daily_energy and energy_yesterday sensors for better state tracking.
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2026-10-05 Update device_wk2168_spi.yaml to version 1.0.3
    Added new booster weika components to the configuration.
2026-10-22 Change external component source to SeByDocKy/myESPhome
    Updated external component source for device configuration.
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2026-10-27 Update device_sx1509.yaml with external components
    Added external components configuration for sx1509.
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
